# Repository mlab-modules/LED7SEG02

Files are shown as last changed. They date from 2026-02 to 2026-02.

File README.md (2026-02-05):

# LED7SEG02 - Project Documentation

Documentation for LED7SEG02 project - 7-segment display with WS2815 addressable RGB LEDs and RS485 communication.

## Project Overview

This project implements control of a 7-segment display consisting of 29 WS2815 RGB LEDs using STM32G031F8Px microcontroller. The display is controlled via RS485 bus using a defined protocol.

### Basic Specifications

- **MCU:** STM32G031F8Px (Cortex-M0+ @ 64MHz)
- **LEDs:** 29× WS2815 RGB (7 segments × 4 LEDs + 1 decimal point)
- **Communication:** RS485 @ 921600 baud
- **Power:** 3.3V (MCU), 12V (LEDs)

## Documentation Structure

### [WS2815_Driver_en.md](WS2815_Driver_en.md)
Complete WS2815 driver documentation including:
- API reference
- Visual effects library
- Usage examples
- Troubleshooting

### [Hardware_Configuration_en.md](Hardware_Configuration_en.md)
Hardware configuration and specifications:
- MCU pinout
- Peripheral settings
- Wiring diagram

### [protocol_en.md](protocol_en.md)
RS485 communication protocol:
- Frame structure
- Command list
- CRC-8 calculation
- Communication examples

### [firmware_en.md](firmware_en.md)
Firmware documentation:
- Software architecture
- Module descriptions
- Data flow

## Quick Start

### 1. Building the Project

Open project in **STM32CubeIDE**:

```
File → Open Projects from File System
→ Import source: LED7SEG02\sw
```

Build project: `Project → Build Project` (Ctrl+B)

### 2. Basic Usage

```c
#include "sw_ws2815.h"
#include "sw_effects.h"

void APP_Init(void) {
    WS2815_Init();
    WS2815_SetBrightness(50);
    Effects_Init();
    RS485_Init();
    Protocol_Init();
    RS485_StartReceive();
}

void APP_Main(void) {
    WS2815_Color_t green = {0, 255, 0};

    // Display digit
    WS2815_DisplayDigit(8, green, 1);
    WS2815_Update();
    while(WS2815_IsBusy());
}
```

### 3. Hardware Connection

```
PA0 (MCU) ──────► DI (WS2815)
GND (MCU) ──────► GND (WS2815)
12V PSU   ──────► +12V (WS2815)

PA2 (MCU) ──────► DI (MAX3485)
PA3 (MCU) ◄────── RO (MAX3485)
PA1 (MCU) ──────► DE/RE (MAX3485)
```

## Project Structure

```
LED7SEG02/
├── doc/                          # Documentation
│   ├── README.md                 # This file (CZ)
│   ├── README_en.md              # This file (EN)
│   ├── WS2815_Driver.md          # Driver documentation (CZ)
│   ├── WS2815_Driver_en.md       # Driver documentation (EN)
│   ├── Hardware_Configuration.md # Hardware documentation (CZ)
│   ├── Hardware_Configuration_en.md # Hardware documentation (EN)
│   ├── protocol_cz.md            # Protocol (CZ)
│   ├── protocol_en.md            # Protocol (EN)
│   ├── firmware_cz.md            # Firmware (CZ)
│   └── firmware_en.md            # Firmware (EN)
├── hw/                           # Hardware design files
├── sw/                           # Firmware
│   ├── Core/                     # STM32 HAL core
│   ├── Drivers/                  # STM32 HAL drivers
│   ├── src/                      # Application code
│   │   ├── app.c
│   │   └── app.h
│   ├── sw/                       # Custom drivers
│   │   ├── sw_ws2815.c/.h        # WS2815 driver
│   │   ├── sw_rs485.c/.h         # RS485 driver
│   │   └── sw_protocol.c/.h      # Communication protocol
│   └── sw_effects/               # Visual effects
│       ├── sw_effects.c/.h
│       └── README.md
└── app/                          # Python test application
    ├── led7seg_test.py
    └── config.json
```

## Key Features

### WS2815 Driver

- Hardware PWM + DMA (no bit-banging)
- 800 kHz bitrate
- Non-blocking operations
- Adjustable brightness (10-254)
- Precise timing (TIM2 @ 64MHz)
- Low CPU usage

### Visual Effects

- Rainbow - rainbow color cycle
- Spinning - spinning LED
- Breathing - breathing effect
- Segment Chase - running segments
- Knight Rider - K.I.T.T. effect
- Loading Bar - progress bar
- Rainbow Digit - digit with changing color
- Rainbow Gradient - digit with rainbow gradient

### RS485 Communication

- 921600 baud, 8N1
- Hardware RS485 mode (automatic DE control)
- Interrupt-based receive/transmit
- IDLE line detection for frame end
- CRC-8 validation
- Response time < 2ms

## Peripheral Configuration

| Peripheral | Pin | Function |
|---|---|---|
| TIM2_CH1 | PA0 | WS2815 Data |
| USART2_TX  | PA2 | RS485 TX |
| USART2_RX  | PA3 | RS485 RX |
| USART2_DE  | PA1 | RS485 Direction  |
| GPIO | PA4 | Address bit 0 |
| GPIO | PA12  | Address bit 1 |
| GPIO | PB0 | Address bit 2 |
| GPIO | PA11  | Address bit 3 |

## Segment Mapping

```
    aaaa
   f    b
   f    b
    gggg
   e    c
   e    c
    dddd  dp
```

| Segment | Index | LED positions |
|---|---|---|
| a | 0 | 0-3 |
| b | 1 | 4-7 |
| c | 2 | 8-11 |
| d | 3 | 12-15 |
| e | 4 | 16-19 |
| f | 5 | 20-23 |
| g | 6 | 24-27 |
| dp | 7 | 28 |

## API Quick Reference

### Initialization

```c
WS2815_Init();                      // Initialize driver
WS2815_SetBrightness(brightness);   // Set brightness (10-254)
Effects_Init();                     // Initialize effects
```

### Display Control

```c
WS2815_DisplayDigit(digit, color, show_dp);  // Display digit 0-9
WS2815_SetSegment(segment, color);           // Set segment
WS2815_SetLED(index, color);                 // Set LED
WS2815_Clear();                              // Turn off all LEDs
```

### Update

```c
WS2815_Update();                    // Send data (non-blocking)
WS2815_IsBusy();                    // Check if busy
```

### Effects

```c
Effects_Rainbow(step);                          // Rainbow effect
Effects_RainbowDigit(digit, show_dp, step);     // Rainbow on digit
Effects_Breathing(step, color);                 // Breathing
Effects_KnightRider(pos, color);                // K.I.T.T.
```

## Troubleshooting

### LEDs not lighting

1. Check 12V power supply
2. Check PA0 → DI wiring
3. Check common ground
4. Verify DMA buffer (WS2815_IsBusy)

### RS485 not communicating

1. Check baud rate (921600)
2. Verify A/B wire connections
3. Check BCD switch address
4. Measure DE pin activity

### Wrong colors

- Check brightness setting (range 10-254)
- Check power supply voltage (min 11V)

## Version History

### v1.0 (2026-02)

- WS2815 driver implementation
- RS485 communication with protocol
- Visual effects library
- Documentation

## License and Author

- **Project:** LED7SEG02
- **Author:** Richard Roztocil
- **Date:** February 2026

## References

- [WS2815 Datasheet](https://cdn-shop.adafruit.com/product-files/2757/WS2815.pdf)
- [STM32G031 Datasheet](https://www.st.com/resource/en/datasheet/stm32g031f8.pdf)
- [MAX3485 Datasheet](https://www.maximintegrated.com/en/products/interface/transceivers/MAX3485.html)

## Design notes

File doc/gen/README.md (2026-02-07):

# PCB

Board size: 74.6x128.54 mm (2.94x5.06 inches)

- This is the size of the rectangle that contains the board
- Thickness: 1.6 mm (63 mils)
- Material: FR4
- Finish: HAL
- Layers: 2
- Copper thickness: 35 µm

Solder mask: TOP / BOTTOM

- Color: Green

Silk screen: TOP / BOTTOM

- Color: White

# Important sizes

Clearance: 0.2 mm (8 mils)

Track width: 0.4 mm (16 mils)

- By design rules: 0.0 mm (0 mils)

Drill: 0.4 mm (16 mils)

- Vias: 0.4 mm (16 mils) [Design: 0.4 mm (16 mils)]
- Pads: 0.6 mm (24 mils)
- The above values are real drill sizes, they add 0.1 mm (4 mils) to plated holes (PTH)

Via: 0.6/0.3 mm (24/12 mils)

- By design rules: 0.5/0.3 mm (20/12 mils)
- Micro via: yes [0.2/0.1 mm (8/4 mils)]
- Buried/blind via: yes
- Total: 144 (thru: 144 buried/blind: 0 micro: 0)

Outer Annular Ring: 0.1 mm (4 mils)

- By design rules: 0.1 mm (4 mils)

Eurocircuits class: 8C
- Using min drill 0.35 mm for an OAR of 0.1 mm

# General stats

Components count: (SMD/THT)

- Top: 85/1 (SMD + THT)
- Bottom: 1/2 (SMD + THT)

Defined tracks:

Used tracks:

- 0.4 mm (16 mils) (474) defined: no
- 1.0 mm (39 mils) (97) defined: no

Defined vias:

Used vias:

- 0.6/0.3 mm (24/12 mils) (Count: 142, Aspect: 2.7 A) defined: no
- 1.0/0.6 mm (39/24 mils) (Count: 2, Aspect: 1.6 A) defined: no

Holes (excluding vias):

- 0.5 mm (20 mils) (5)
- 1.0 mm (39 mils) (12)

Oval holes:

Drill tools (including vias and computing adjusts and rounding):

- 0.4 mm (16 mils) (142)
- 0.6 mm (24 mils) (5)
- 0.7 mm (28 mils) (2)
- 1.1 mm (43 mils) (12)

Solder paste stats:

Using a paste with 87.75 % alloy, that has an specific gravity for the alloy of 7.4 g/cm³
and 1.0 g/cm³ for the flux. This paste has an specific gravity of  4.15 g/cm³.

The stencil thickness is  0.12 mm.

| Side | Pads with paste | Area [mm²] | Paste [g] |
|---|---|---|---|
| Top | 315 | 543.56 | 2.71 |
| Bottom | 6 | 18.00 | 0.09 |
| Total  | 321 | 561.56 | 2.80 |

Note: this is just an approximation to the theoretical value. Margins of the solder mask and waste aren't computed.

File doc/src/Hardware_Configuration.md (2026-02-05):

# LED7SEG02 - Hardware konfigurace

## MCU Specifikace

- **MCU:** STM32G031F8Px
- **Package:** TSSOP20
- **Core:** ARM Cortex-M0+ @ 64 MHz
- **Flash:** 64 KB
- **RAM:** 8 KB
- **Voltage:** 2.0V - 3.6V

## System Clock Configuration

```
HSI (16 MHz)
  └─> PLL (×8, ÷2)
       └─> SYSCLK: 64 MHz
            ├─> AHB: 64 MHz
            └─> APB: 64 MHz
```

### Clock Settings

```c
RCC_OscInitStruct.OscillatorType = RCC_OSCILLATORTYPE_HSI;
RCC_OscInitStruct.HSIState = RCC_HSI_ON;
RCC_OscInitStruct.HSIDiv = RCC_HSI_DIV1;
RCC_OscInitStruct.PLL.PLLState = RCC_PLL_ON;
RCC_OscInitStruct.PLL.PLLSource = RCC_PLLSOURCE_HSI;
RCC_OscInitStruct.PLL.PLLM = RCC_PLLM_DIV1;
RCC_OscInitStruct.PLL.PLLN = 8;
RCC_OscInitStruct.PLL.PLLR = RCC_PLLR_DIV2;
```

## Pinout

### Port A

| Pin | Funkce | Mód | Popis |
|-----|---|---|---|
| PA0 | TIM2_CH1 | AF | **WS2815 Data Output** |
| PA1 | USART2_DE | AF | RS485 Direction Enable |
| PA2 | USART2_TX | AF | RS485 Transmit |
| PA3 | USART2_RX | AF | RS485 Receive |
| PA4 | addr_0 | Input Pull-up | Adresa bit 0 (active LOW)  |
| PA11| addr_3 | Input Pull-up | Adresa bit 3 (active LOW)  |
| PA12| addr_1 | Input Pull-up | Adresa bit 1 (active LOW)  |
| PA13| SWDIO | Debug | SWD Data |
| PA14| SWCLK | Debug | SWD Clock |

### Port B

| Pin | Funkce | Mód | Popis |
|-----|---|---|---|
| PB0 | addr_2 | Input Pull-up | Adresa bit 2 (active LOW)  |

## Konfigurace periférií

### TIM2 (WS2815 PWM)

**Účel:** Generování přesného PWM signálu pro WS2815 LED protokol

```c
htim2.Instance = TIM2;
htim2.Init.Prescaler = 0;              // Bez dělení
htim2.Init.CounterMode = TIM_COUNTERMODE_UP;
htim2.Init.Period = 79;                // 1.25µs @ 64MHz
htim2.Init.ClockDivision = TIM_CLOCKDIVISION_DIV1;
htim2.Init.AutoReloadPreload = TIM_AUTORELOAD_PRELOAD_ENABLE;
```

**Channel 1 (PA0):**
- Mode: PWM Mode 1
- Duty cycle: Variable (24 nebo 52) pro bit encoding
- Řízeno DMA

### DMA1 Channel 1 (WS2815)

```c
hdma_ws2815.Instance = DMA1_Channel1;
hdma_ws2815.Init.Request = DMA_REQUEST_TIM2_CH1;
hdma_ws2815.Init.Direction = DMA_MEMORY_TO_PERIPH;
hdma_ws2815.Init.PeriphInc = DMA_PINC_DISABLE;
hdma_ws2815.Init.MemInc = DMA_MINC_ENABLE;
hdma_ws2815.Init.PeriphDataAlignment = DMA_PDATAALIGN_HALFWORD;
hdma_ws2815.Init.MemDataAlignment = DMA_MDATAALIGN_HALFWORD;
hdma_ws2815.Init.Mode = DMA_NORMAL;
hdma_ws2815.Init.Priority = DMA_PRIORITY_HIGH;
```

### USART2 (RS485)

**Účel:** RS485 komunikační rozhraní

```c
huart2.Instance = USART2;
huart2.Init.BaudRate = 921600;
huart2.Init.WordLength = UART_WORDLENGTH_8B;
huart2.Init.StopBits = UART_STOPBITS_1;
huart2.Init.Parity = UART_PARITY_NONE;
huart2.Init.Mode = UART_MODE_TX_RX;
huart2.Init.HwFlowCtl = UART_HWCONTROL_NONE;
huart2.Init.OverSampling = UART_OVERSAMPLING_16;
```

**RS485 Mode:**
- DE polarity: High
- DE assertion: 0 bit times
- DE deassertion: 0 bit times
- Automatické řízení DE pinu (hardware RS485 mode)

## GPIO Configuration

### WS2815 Data Pin (PA0)

```c
GPIO_InitStruct.Pin = GPIO_PIN_0;
GPIO_InitStruct.Mode = GPIO_MODE_AF_PP;      // Alternate Function Push-Pull
GPIO_InitStruct.Pull = GPIO_NOPULL;
GPIO_InitStruct.Speed = GPIO_SPEED_FREQ_HIGH;
GPIO_InitStruct.Alternate = GPIO_AF2_TIM2;   // TIM2_CH1
```

### RS485 Pins

```c
// TX (PA2) a RX (PA3)
GPIO_InitStruct.Pin = GPIO_PIN_2 | GPIO_PIN_3;
GPIO_InitStruct.Mode = GPIO_MODE_AF_PP;
GPIO_InitStruct.Pull = GPIO_NOPULL;
GPIO_InitStruct.Speed = GPIO_SPEED_FREQ_HIGH;
GPIO_InitStruct.Alternate = GPIO_AF1_USART2;

// DE (PA1)
GPIO_InitStruct.Pin = GPIO_PIN_1;
GPIO_InitStruct.Mode = GPIO_MODE_AF_PP;
GPIO_InitStruct.Pull = GPIO_NOPULL;
GPIO_InitStruct.Speed = GPIO_SPEED_FREQ_HIGH;
GPIO_InitStruct.Alternate = GPIO_AF1_USART2;
```

### Address Pins (BCD Switch)

```c
// addr_0 (PA4), addr_1 (PA12), addr_3 (PA11)
GPIO_InitStruct.Pin = GPIO_PIN_4 | GPIO_PIN_11 | GPIO_PIN_12;
GPIO_InitStruct.Mode = GPIO_MODE_INPUT;
GPIO_InitStruct.Pull = GPIO_PULLUP;

// addr_2 (PB0)
GPIO_InitStruct.Pin = GPIO_PIN_0;
GPIO_InitStruct.Mode = GPIO_MODE_INPUT;
GPIO_InitStruct.Pull = GPIO_PULLUP;
```

**Poznámka:** Adresové piny jsou aktivní v LOW (sepnutý přepínač = 0)

## Interrupt Configuration

### NVIC Priorities

| Přerušení | Priorita | Popis |
|---|---|---|
| DMA1_Channel1_IRQn  | 0 | WS2815 DMA (nejvyšší) |
| USART2_IRQn | 1 | RS485 komunikace |
| SysTick_IRQn | 3 | System tick timer |

### DMA1_Channel1_IRQHandler

```c
void DMA1_Channel1_IRQHandler(void)
{
    HAL_DMA_IRQHandler(&hdma_ws2815);
}
```

### USART2_IRQHandler

```c
void USART2_IRQHandler(void)
{
    RS485_IRQHandler();
}
```

## Schéma zapojení

### WS2815 LED Strip

```
STM32G031F8Px                    WS2815 LED Strip
┌─────────────┐                  ┌──────────┐
│             │                  │          │
│  PA0 (TIM2) ├─────────────────►│ DI       │
│             │   (Data)         │          │
│         GND ├─────────────────►│ GND      │
│             │                  │          │
└─────────────┘                  │ +12V     │◄─── 12V PSU
                                 └──────────┘
```

### RS485 Transceiver (MAX3485)

```
STM32G031F8Px                    MAX3485
┌─────────────┐                  ┌──────────┐
│             │                  │          │
│  PA2 (TX)   ├─────────────────►│ DI       │
│             │                  │          │
│  PA3 (RX)   │◄─────────────────┤ RO       │
│             │                  │          │
│  PA1 (DE)   ├─────────────────►│ DE       │
│             │        ┌────────►│ /RE      │
│             │        │         │          │
│         GND ├────────┴────────►│ GND      │
│             │                  │          │
│        3.3V ├─────────────────►│ VCC      │
│             │                  │          │
└─────────────┘                  │ A  ◄────►│ RS485 Bus
                                 │ B  ◄────►│
                                 └──────────┘
```

**Poznámka:** DE a /RE jsou spojeny - řízeny z PA1

### BCD Address Switch

```
STM32G031F8Px                    BCD Switch
┌─────────────┐                  ┌──────────┐
│             │                  │          │
│  PA4 (addr0)│◄─────────────────┤ bit 0    │
│             │                  │          │
│  PA12(addr1)│◄─────────────────┤ bit 1    │
│             │                  │          │
│  PB0 (addr2)│◄─────────────────┤ bit 2    │
│             │                  │          │
│  PA11(addr3)│◄─────────────────┤ bit 3    │
│             │                  │          │
│         GND ├─────────────────►│ Common   │
│             │                  │          │
└─────────────┘                  └──────────┘
```

**Poznámka:** Přepínače jsou aktivní v LOW (sepnutý = GND = 0)

## Poznámky k připojení

### Napájení

1. **MCU (3.3V):**
   - 100nF keramický kondenzátor na VDD/VSS (blízko MCU)
   - 10µF tantalový kondenzátor na VDD/VSS

2. **WS2815 (12V):**
   - Proud: ~60mA per LED při full white
   - Pro 29 LED: ~1.8A max
   - 1000µF elektrolytický kondenzátor na 12V vstupu

### Datová linka WS2815

- PA0 (3.3V logic) přímo na WS2815 DI
- Volitelně: 330Ω sériový rezistor pro ochranu
- Max délka kabelu: 5 metrů

### RS485 Bus

- Zakončovací odpor 120Ω na obou koncích sběrnice
- Twisted pair pro A/B vodiče
- Společná zem mezi zařízeními

## Spotřeba

### MCU

- Active mode @ 64MHz: ~15 mA
- Sleep mode: ~2 mA
- Stop mode: ~2 µA

### WS2815 LEDs

Per LED při 50% brightness:
- Red: 20 mA
- Green: 20 mA
- Blue: 20 mA
- White: 60 mA

Celkem pro 29 LED:
- All off: 0 mA
- All white @ 50%: ~0.9 A
- All white @ 100%: ~1.8 A

## Memory Map

### Flash (64 KB)

```
0x0800 0000 - 0x0800 FFFF    Flash memory
0x0800 0000 - 0x0800 0200    Interrupt vectors
0x0800 0200 - 0x0800 XXXX    Application code
0x0800 XXXX - 0x0800 FFFF    Constants/data
```

### RAM (8 KB)

```
0x2000 0000 - 0x2000 1FFF    SRAM
```

### RAM využití

| Buffer | Velikost | Popis |
|---|---|---|
| DMA buffer | ~2 KB | WS2815 data (29 LED × 24 bit + reset) |
| RX ring buffer | 64 B | RS485 příjem |
| TX buffer | 64 B | RS485 odesílání |
| Frame buffer | 64 B | Příchozí rámec |
| Response buffer | 13 B | Odpověď |

## HAL Configuration

### stm32g0xx_hal_conf.h

Povinné moduly:

```c
#define HAL_MODULE_ENABLED
#define HAL_TIM_MODULE_ENABLED      // Required for TIM2
#define HAL_DMA_MODULE_ENABLED      // Required for DMA
#define HAL_GPIO_MODULE_ENABLED
#define HAL_RCC_MODULE_ENABLED
#define HAL_CORTEX_MODULE_ENABLED
#define HAL_UART_MODULE_ENABLED     // For RS485
```

## Debug Configuration

### SWD

- **SWDIO:** PA13
- **SWCLK:** PA14

## Checklist pro oživení

- [ ] 3.3V napájení stabilní
- [ ] System clock 64 MHz ověřen
- [ ] SWD připojení funkční
- [ ] PA0 konfigurován jako TIM2_CH1
- [ ] TIM2 clock povolen
- [ ] DMA1 clock povolen
- [ ] WS2815 12V napájení připojeno
- [ ] Společná zem mezi MCU a LED
- [ ] První LED svítí s test kódem
- [ ] Všech 29 LED adresovatelných
- [ ] RS485 komunikace funkční
- [ ] BCD adresa správně čtena

## Troubleshooting

### PA0 nevysílá signál

1. Zkontrolovat GPIO clock: `__HAL_RCC_GPIOA_CLK_ENABLE()`
2. Zkontrolovat TIM2 clock: `__HAL_RCC_TIM2_CLK_ENABLE()`
3. Zkontrolovat alternate function: `GPIO_AF2_TIM2`
4. Měřit osciloskopem: Měl by být ~800kHz signál

### DMA nefunguje

1. Zkontrolovat DMA1 clock: `__HAL_RCC_DMA1_CLK_ENABLE()`
2. Zkontrolovat DMA request: `DMA_REQUEST_TIM2_CH1`
3. Zkontrolovat NVIC: `HAL_NVIC_EnableIRQ(DMA1_Channel1_IRQn)`
4. Zkontrolovat TIM2 DMA: `__HAL_TIM_ENABLE_DMA(&htim2, TIM_DMA_CC1)`

### RS485 nekomunikuje

1. Zkontrolovat baudrate (921600)
2. Zkontrolovat A/B zapojení (může být přehozené)
3. Měřit DE pin aktivitu při odesílání
4. Zkontrolovat zakončovací odpory

### Špatná adresa

1. Zkontrolovat pull-up na adresových pinech
2. Zkontrolovat že přepínače spínají k GND
3. Testovat jednotlivé bity

## Reference

- [STM32G031 Datasheet](https://www.st.com/resource/en/datasheet/stm32g031f8.pdf)
- [STM32G0 Reference Manual RM0444](https://www.st.com/resource/en/reference_manual/rm0444-stm32g0x0-advanced-armbased-32bit-mcus-stmicroelectronics.pdf)
- [WS2815 Datasheet](https://cdn-shop.adafruit.com/product-files/2757/WS2815.pdf)
- [MAX3485 Datasheet](https://www.maximintegrated.com/en/products/interface/transceivers/MAX3485.html)

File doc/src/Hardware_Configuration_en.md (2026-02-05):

# LED7SEG02 - Hardware Configuration

## MCU Specifications

- **MCU:** STM32G031F8Px
- **Package:** TSSOP20
- **Core:** ARM Cortex-M0+ @ 64 MHz
- **Flash:** 64 KB
- **RAM:** 8 KB
- **Voltage:** 2.0V - 3.6V

## System Clock Configuration

```
HSI (16 MHz)
  └─> PLL (×8, ÷2)
       └─> SYSCLK: 64 MHz
            ├─> AHB: 64 MHz
            └─> APB: 64 MHz
```

### Clock Settings

```c
RCC_OscInitStruct.OscillatorType = RCC_OSCILLATORTYPE_HSI;
RCC_OscInitStruct.HSIState = RCC_HSI_ON;
RCC_OscInitStruct.HSIDiv = RCC_HSI_DIV1;
RCC_OscInitStruct.PLL.PLLState = RCC_PLL_ON;
RCC_OscInitStruct.PLL.PLLSource = RCC_PLLSOURCE_HSI;
RCC_OscInitStruct.PLL.PLLM = RCC_PLLM_DIV1;
RCC_OscInitStruct.PLL.PLLN = 8;
RCC_OscInitStruct.PLL.PLLR = RCC_PLLR_DIV2;
```

## Pinout

### Port A

| Pin | Function | Mode | Description |
|-----|---|---|---|
| PA0 | TIM2_CH1 | AF | **WS2815 Data Output** |
| PA1 | USART2_DE | AF | RS485 Direction Enable |
| PA2 | USART2_TX | AF | RS485 Transmit |
| PA3 | USART2_RX | AF | RS485 Receive |
| PA4 | addr_0 | Input Pull-up | Address bit 0 (active LOW) |
| PA11| addr_3 | Input Pull-up | Address bit 3 (active LOW) |
| PA12| addr_1 | Input Pull-up | Address bit 1 (active LOW) |
| PA13| SWDIO | Debug | SWD Data |
| PA14| SWCLK | Debug | SWD Clock |

### Port B

| Pin | Function | Mode | Description |
|-----|---|---|---|
| PB0 | addr_2 | Input Pull-up | Address bit 2 (active LOW) |

## Peripheral Configuration

### TIM2 (WS2815 PWM)

**Purpose:** Generate precise PWM signal for WS2815 LED protocol

```c
htim2.Instance = TIM2;
htim2.Init.Prescaler = 0;              // No prescaling
htim2.Init.CounterMode = TIM_COUNTERMODE_UP;
htim2.Init.Period = 79;                // 1.25µs @ 64MHz
htim2.Init.ClockDivision = TIM_CLOCKDIVISION_DIV1;
htim2.Init.AutoReloadPreload = TIM_AUTORELOAD_PRELOAD_ENABLE;
```

**Channel 1 (PA0):**
- Mode: PWM Mode 1
- Duty cycle: Variable (24 or 52) for bit encoding
- Driven by DMA

### DMA1 Channel 1 (WS2815)

```c
hdma_ws2815.Instance = DMA1_Channel1;
hdma_ws2815.Init.Request = DMA_REQUEST_TIM2_CH1;
hdma_ws2815.Init.Direction = DMA_MEMORY_TO_PERIPH;
hdma_ws2815.Init.PeriphInc = DMA_PINC_DISABLE;
hdma_ws2815.Init.MemInc = DMA_MINC_ENABLE;
hdma_ws2815.Init.PeriphDataAlignment = DMA_PDATAALIGN_HALFWORD;
hdma_ws2815.Init.MemDataAlignment = DMA_MDATAALIGN_HALFWORD;
hdma_ws2815.Init.Mode = DMA_NORMAL;
hdma_ws2815.Init.Priority = DMA_PRIORITY_HIGH;
```

### USART2 (RS485)

**Purpose:** RS485 communication interface

```c
huart2.Instance = USART2;
huart2.Init.BaudRate = 921600;
huart2.Init.WordLength = UART_WORDLENGTH_8B;
huart2.Init.StopBits = UART_STOPBITS_1;
huart2.Init.Parity = UART_PARITY_NONE;
huart2.Init.Mode = UART_MODE_TX_RX;
huart2.Init.HwFlowCtl = UART_HWCONTROL_NONE;
huart2.Init.OverSampling = UART_OVERSAMPLING_16;
```

**RS485 Mode:**
- DE polarity: High
- DE assertion: 0 bit times
- DE deassertion: 0 bit times
- Automatic DE pin control (hardware RS485 mode)

## GPIO Configuration

### WS2815 Data Pin (PA0)

```c
GPIO_InitStruct.Pin = GPIO_PIN_0;
GPIO_InitStruct.Mode = GPIO_MODE_AF_PP;      // Alternate Function Push-Pull
GPIO_InitStruct.Pull = GPIO_NOPULL;
GPIO_InitStruct.Speed = GPIO_SPEED_FREQ_HIGH;
GPIO_InitStruct.Alternate = GPIO_AF2_TIM2;   // TIM2_CH1
```

### RS485 Pins

```c
// TX (PA2) and RX (PA3)
GPIO_InitStruct.Pin = GPIO_PIN_2 | GPIO_PIN_3;
GPIO_InitStruct.Mode = GPIO_MODE_AF_PP;
GPIO_InitStruct.Pull = GPIO_NOPULL;
GPIO_InitStruct.Speed = GPIO_SPEED_FREQ_HIGH;
GPIO_InitStruct.Alternate = GPIO_AF1_USART2;

// DE (PA1)
GPIO_InitStruct.Pin = GPIO_PIN_1;
GPIO_InitStruct.Mode = GPIO_MODE_AF_PP;
GPIO_InitStruct.Pull = GPIO_NOPULL;
GPIO_InitStruct.Speed = GPIO_SPEED_FREQ_HIGH;
GPIO_InitStruct.Alternate = GPIO_AF1_USART2;
```

### Address Pins (BCD Switch)

```c
// addr_0 (PA4), addr_1 (PA12), addr_3 (PA11)
GPIO_InitStruct.Pin = GPIO_PIN_4 | GPIO_PIN_11 | GPIO_PIN_12;
GPIO_InitStruct.Mode = GPIO_MODE_INPUT;
GPIO_InitStruct.Pull = GPIO_PULLUP;

// addr_2 (PB0)
GPIO_InitStruct.Pin = GPIO_PIN_0;
GPIO_InitStruct.Mode = GPIO_MODE_INPUT;
GPIO_InitStruct.Pull = GPIO_PULLUP;
```

**Note:** Address pins are active LOW (closed switch = 0)

## Interrupt Configuration

### NVIC Priorities

| Interrupt | Priority | Description |
|---|---|---|
| DMA1_Channel1_IRQn  | 0 | WS2815 DMA (highest) |
| USART2_IRQn | 1 | RS485 communication |
| SysTick_IRQn | 3 | System tick timer |

### DMA1_Channel1_IRQHandler

```c
void DMA1_Channel1_IRQHandler(void)
{
    HAL_DMA_IRQHandler(&hdma_ws2815);
}
```

### USART2_IRQHandler

```c
void USART2_IRQHandler(void)
{
    RS485_IRQHandler();
}
```

## Wiring Diagrams

### WS2815 LED Strip

```
STM32G031F8Px                    WS2815 LED Strip
┌─────────────┐                  ┌──────────┐
│             │                  │          │
│  PA0 (TIM2) ├─────────────────►│ DI       │
│             │   (Data)         │          │
│         GND ├─────────────────►│ GND      │
│             │                  │          │
└─────────────┘                  │ +12V     │◄─── 12V PSU
                                 └──────────┘
```

### RS485 Transceiver (MAX3485)

```
STM32G031F8Px                    MAX3485
┌─────────────┐                  ┌──────────┐
│             │                  │          │
│  PA2 (TX)   ├─────────────────►│ DI       │
│             │                  │          │
│  PA3 (RX)   │◄─────────────────┤ RO       │
│             │                  │          │
│  PA1 (DE)   ├─────────────────►│ DE       │
│             │        ┌────────►│ /RE      │
│             │        │         │          │
│         GND ├────────┴────────►│ GND      │
│             │                  │          │
│        3.3V ├─────────────────►│ VCC      │
│             │                  │          │
└─────────────┘                  │ A  ◄────►│ RS485 Bus
                                 │ B  ◄────►│
                                 └──────────┘
```

**Note:** DE and /RE are connected - controlled from PA1

### BCD Address Switch

```
STM32G031F8Px                    BCD Switch
┌─────────────┐                  ┌──────────┐
│             │                  │          │
│  PA4 (addr0)│◄─────────────────┤ bit 0    │
│             │                  │          │
│  PA12(addr1)│◄─────────────────┤ bit 1    │
│             │                  │          │
│  PB0 (addr2)│◄─────────────────┤ bit 2    │
│             │                  │          │
│  PA11(addr3)│◄─────────────────┤ bit 3    │
│             │                  │          │
│         GND ├─────────────────►│ Common   │
│             │                  │          │
└─────────────┘                  └──────────┘
```

**Note:** Switches are active LOW (closed = GND = 0)

## Connection Notes

### Power Supply

1. **MCU (3.3V):**
   - 100nF ceramic capacitor on VDD/VSS (close to MCU)
   - 10µF tantalum capacitor on VDD/VSS

2. **WS2815 (12V):**
   - Current: ~60mA per LED at full white
   - For 29 LEDs: ~1.8A max
   - 1000µF electrolytic capacitor on 12V input

### WS2815 Data Line

- PA0 (3.3V logic) directly to WS2815 DI
- Optional: 330Ω series resistor for protection
- Max cable length: 5 meters

### RS485 Bus

- 120Ω termination resistor at both ends of bus
- Twisted pair for A/B wires
- Common ground between devices

## Power Consumption

### MCU

- Active mode @ 64MHz: ~15 mA
- Sleep mode: ~2 mA
- Stop mode: ~2 µA

### WS2815 LEDs

Per LED at 50% brightness:
- Red: 20 mA
- Green: 20 mA
- Blue: 20 mA
- White: 60 mA

Total for 29 LEDs:
- All off: 0 mA
- All white @ 50%: ~0.9 A
- All white @ 100%: ~1.8 A

## Memory Map

### Flash (64 KB)

```
0x0800 0000 - 0x0800 FFFF    Flash memory
0x0800 0000 - 0x0800 0200    Interrupt vectors
0x0800 0200 - 0x0800 XXXX    Application code
0x0800 XXXX - 0x0800 FFFF    Constants/data
```

### RAM (8 KB)

```
0x2000 0000 - 0x2000 1FFF    SRAM
```

### RAM Usage

| Buffer | Size | Description |
|---|---|---|
| DMA buffer | ~2 KB | WS2815 data (29 LEDs × 24 bits + reset) |
| RX ring buffer | 64 B | RS485 reception |
| TX buffer | 64 B | RS485 transmission |
| Frame buffer | 64 B | Incoming frame |
| Response buffer | 13 B | Response |

## HAL Configuration

### stm32g0xx_hal_conf.h

Required modules:

```c
#define HAL_MODULE_ENABLED
#define HAL_TIM_MODULE_ENABLED      // Required for TIM2
#define HAL_DMA_MODULE_ENABLED      // Required for DMA
#define HAL_GPIO_MODULE_ENABLED
#define HAL_RCC_MODULE_ENABLED
#define HAL_CORTEX_MODULE_ENABLED
#define HAL_UART_MODULE_ENABLED     // For RS485
```

## Debug Configuration

### SWD

- **SWDIO:** PA13
- **SWCLK:** PA14

## Board Bring-up Checklist

- [ ] 3.3V power supply stable
- [ ] System clock 64 MHz verified
- [ ] SWD connection working
- [ ] PA0 configured as TIM2_CH1
- [ ] TIM2 clock enabled
- [ ] DMA1 clock enabled
- [ ] WS2815 12V power supply connected
- [ ] Common ground between MCU and LEDs
- [ ] First LED lights up with test code
- [ ] All 29 LEDs addressable
- [ ] RS485 communication working
- [ ] BCD address read correctly

## Troubleshooting

### PA0 not outputting signal

1. Check GPIO clock: `__HAL_RCC_GPIOA_CLK_ENABLE()`
2. Check TIM2 clock: `__HAL_RCC_TIM2_CLK_ENABLE()`
3. Check alternate function: `GPIO_AF2_TIM2`
4. Measure with oscilloscope: Should see ~800kHz signal

### DMA not working

1. Check DMA1 clock: `__HAL_RCC_DMA1_CLK_ENABLE()`
2. Check DMA request: `DMA_REQUEST_TIM2_CH1`
3. Check NVIC: `HAL_NVIC_EnableIRQ(DMA1_Channel1_IRQn)`
4. Check TIM2 DMA: `__HAL_TIM_ENABLE_DMA(&htim2, TIM_DMA_CC1)`

### RS485 not communicating

1. Check baud rate (921600)
2. Check A/B wiring (may be swapped)
3. Measure DE pin activity during transmission
4. Check termination resistors

### Wrong address

1. Check pull-up on address pins
2. Check that switches connect to GND
3. Test individual bits

## References

- [STM32G031 Datasheet](https://www.st.com/resource/en/datasheet/stm32g031f8.pdf)
- [STM32G0 Reference Manual RM0444](https://www.st.com/resource/en/reference_manual/rm0444-stm32g0x0-advanced-armbased-32bit-mcus-stmicroelectronics.pdf)
- [WS2815 Datasheet](https://cdn-shop.adafruit.com/product-files/2757/WS2815.pdf)
- [MAX3485 Datasheet](https://www.maximintegrated.com/en/products/interface/transceivers/MAX3485.html)

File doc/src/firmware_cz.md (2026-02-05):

# LED7SEG02 - Dokumentace firmware

## Přehled

Firmware pro 7-segmentový displej s adresovatelnými RGB LED WS2815 a RS485 komunikací.

### Hardware

- **MCU**: STM32G031F8PX (Cortex-M0+, 64KB Flash, 8KB RAM)
- **Taktování**: 64 MHz
- **LED**: WS2815 RGB (29 LED - 7 segmentů × 4 LED + 1 desetinná tečka)
- **Komunikace**: RS485 přes MAX3485 transceiver
- **Napájení**: 12V pro WS2815

### Pinout

| Pin | Funkce | Popis |
|-----|---|---|
| PA2 | USART2_TX | RS485 TX (k MAX3485 DI) |
| PA3 | USART2_RX | RS485 RX (z MAX3485 RO) |
| PA1 | USART2_DE | RS485 DE/RE řízení |
| PA0 | TIM2_CH1 | WS2815 data (přes DMA) |
| PA4 | GPIO Input | Adresa bit 0 |
| PA12 | GPIO Input | Adresa bit 1 |
| PB0 | GPIO Input | Adresa bit 2 |
| PA11 | GPIO Input | Adresa bit 3 |

## Architektura software

### Struktura projektu

```
sw/
├── Core/                    # STM32 HAL a konfigurace
│   ├── Inc/
│   └── Src/
│       ├── main.c          # Hlavní smyčka, inicializace
│       ├── stm32g0xx_it.c  # Interrupt handlery
│       └── stm32g0xx_hal_msp.c
├── src/
│   ├── app.c               # Aplikační logika
│   └── app.h
├── sw/
│   ├── sw_ws2815.c/.h      # WS2815 LED driver
│   ├── sw_rs485.c/.h       # RS485 driver
│   └── sw_protocol.c/.h    # Komunikační protokol
└── sw_effects/
    ├── sw_effects.c/.h     # Vizuální efekty
    └── README.md
```

### Moduly

#### sw_ws2815 - WS2815 Driver

Ovládání adresovatelných RGB LED pomocí TIM3 + DMA.

**Časování WS2815:**
- Perioda: 1.25µs (800kHz)
- T0H: 375ns, T0L: 875ns
- T1H: 812.5ns, T1L: 437.5ns
- Reset: >280µs

**Hlavní funkce:**
```c
void WS2815_Init(void);
void WS2815_SetLED(uint8_t index, WS2815_Color_t color);
void WS2815_SetSegment(uint8_t segment, WS2815_Color_t color);
void WS2815_DisplayDigit(uint8_t digit, WS2815_Color_t color, uint8_t show_dp);
void WS2815_SetBrightness(uint8_t brightness);
void WS2815_Update(void);
void WS2815_Clear(void);
uint8_t WS2815_IsBusy(void);
```

#### sw_rs485 - RS485 Driver

Interrupt-based RS485 komunikace s ring bufferem.

**Vlastnosti:**
- RXNE interrupt pro příjem bytů
- IDLE line detection pro detekci konce rámce
- TXE/TC interrupts pro odesílání
- Hardware RS485 mód (automatické DE řízení)

**Hlavní funkce:**
```c
RS485_Status_t RS485_Init(void);
RS485_Status_t RS485_StartReceive(void);
RS485_Status_t RS485_TransmitIT(uint8_t *data, uint16_t length);
void RS485_SetFrameCallback(RS485_FrameCallback_t callback);
uint8_t RS485_Available(void);
uint8_t RS485_Read(void);
void RS485_IRQHandler(void);
```

#### sw_protocol - Komunikační protokol

Zpracování příkazů a odpovědí.

**Vlastnosti:**
- Zpracování rámce v IDLE přerušení (minimální latence)
- Odložená aktualizace displeje (DMA safe)
- CRC-8 validace

**Hlavní funkce:**
```c
void Protocol_Init(void);
void Protocol_Process(void);
void Protocol_HandleFrame(uint8_t *data, uint8_t length);
uint8_t Protocol_GetAddress(void);
```

#### sw_effects - Vizuální efekty

Knihovna předpřipravených animací.

**Dostupné efekty:**
- Rainbow - duhový cyklus
- Spinning - kroužící LED
- Breathing - dýchací efekt
- Segment Chase - běžící segmenty
- Knight Rider - K.I.T.T. efekt
- Loading Bar - progress bar
- Rainbow Digit - číslice s měnící se barvou
- Rainbow Gradient - číslice s duhovým gradientem

## Tok dat

### Příjem a zpracování příkazu

```
1. RXNE interrupt → byte do ring bufferu a frame bufferu
2. IDLE interrupt → Protocol_HandleFrame() volán
3. Rámec parsován a validován (CRC)
4. Příkaz zpracován, stav aktualizován
5. Odpověď odeslána (TX interrupt)
6. display_update_pending flag nastaven
7. Main loop → Protocol_Process() → UpdateDisplay()
8. WS2815_Update() → DMA transfer → LED aktualizovány
```

### Časování odpovědi

- Firmware zpracování: <100µs
- Celková odezva: ~1.5ms (limitováno USB převodníkem)

## Konfigurace

### USART2 (RS485)

```c
BaudRate = 921600
WordLength = 8 bits
StopBits = 1
Parity = None
Mode = TX_RX
HwFlowCtl = None
OverSampling = 16
DE Polarity = High
```

### TIM3 (WS2815)

```c
Prescaler = 0
Period = 79 (80 cyklů = 1.25µs při 64MHz)
Channel 1 PWM mode
DMA Circular mode
```

### NVIC Priority

| Přerušení | Priorita | Popis |
|---|---|---|
| DMA1_Channel1 | 0 | WS2815 (nejvyšší) |
| USART2 | 1 | RS485 komunikace |
| SysTick | 3 | HAL timing |

## Paměťová mapa

| Oblast | Velikost | Použití |
|---|---|---|
| Flash | 64 KB | Kód + konstanty |
| RAM | 8 KB | Proměnné + buffery |

### RAM využití

| Buffer | Velikost | Popis |
|---|---|---|
| DMA buffer | ~2 KB | WS2815 data (29 LED × 24 bit + reset) |
| RX ring buffer | 64 B | RS485 příjem |
| TX buffer | 64 B | RS485 odesílání |
| Frame buffer | 64 B | Příchozí rámec |
| Response buffer | 13 B | Odpověď |

## Kompilace a programování

### Požadavky

- STM32CubeIDE nebo ARM GCC toolchain
- ST-Link programmer

### Kompilace

```bash
cd sw/Debug
make clean
make all
```

### Programování

```bash
st-flash write LED7SEG02.bin 0x08000000
```

Nebo pomocí STM32CubeIDE: Run → Debug/Run

## Řešení problémů

### LED nesvítí

1. Zkontrolujte 12V napájení
2. Ověřte DMA buffer (WS2815_IsBusy)
3. Zkontrolujte timing signálu osciloskopem

### RS485 nekomunikuje

1. Zkontrolujte baudrate (921600)
2. Ověřte zapojení A/B vodičů
3. Zkontrolujte adresu BCD přepínačů
4. Změřte DE pin aktivitu

### Pomalá odezva

1. Ověřte zpracování v IDLE přerušení
2. Zkontrolujte priority přerušení
3. USB převodník může být bottleneck

## Verze

| Verze | Datum | Změny |
|---|---|---|
| 1.0 | 2026-02 | První verze |

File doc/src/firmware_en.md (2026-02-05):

# LED7SEG02 - Firmware Documentation

## Overview

Firmware for 7-segment display with addressable WS2815 RGB LEDs and RS485 communication.

### Hardware

- **MCU**: STM32G031F8PX (Cortex-M0+, 64KB Flash, 8KB RAM)
- **Clock**: 64 MHz
- **LEDs**: WS2815 RGB (29 LEDs - 7 segments × 4 LEDs + 1 decimal point)
- **Communication**: RS485 via MAX3485 transceiver
- **Power**: 12V for WS2815

### Pinout

| Pin | Function | Description |
|-----|---|---|
| PA2 | USART2_TX | RS485 TX (to MAX3485 DI) |
| PA3 | USART2_RX | RS485 RX (from MAX3485 RO) |
| PA1 | USART2_DE | RS485 DE/RE control |
| PA0 | TIM2_CH1 | WS2815 data (via DMA) |
| PA4 | GPIO Input | Address bit 0 |
| PA12 | GPIO Input | Address bit 1 |
| PB0 | GPIO Input | Address bit 2 |
| PA11 | GPIO Input | Address bit 3 |

## Software Architecture

### Project Structure

```
sw/
├── Core/                    # STM32 HAL and configuration
│   ├── Inc/
│   └── Src/
│       ├── main.c          # Main loop, initialization
│       ├── stm32g0xx_it.c  # Interrupt handlers
│       └── stm32g0xx_hal_msp.c
├── src/
│   ├── app.c               # Application logic
│   └── app.h
├── sw/
│   ├── sw_ws2815.c/.h      # WS2815 LED driver
│   ├── sw_rs485.c/.h       # RS485 driver
│   └── sw_protocol.c/.h    # Communication protocol
└── sw_effects/
    ├── sw_effects.c/.h     # Visual effects
    └── README.md
```

### Modules

#### sw_ws2815 - WS2815 Driver

Controls addressable RGB LEDs using TIM3 + DMA.

**WS2815 Timing:**
- Period: 1.25µs (800kHz)
- T0H: 375ns, T0L: 875ns
- T1H: 812.5ns, T1L: 437.5ns
- Reset: >280µs

**Main Functions:**
```c
void WS2815_Init(void);
void WS2815_SetLED(uint8_t index, WS2815_Color_t color);
void WS2815_SetSegment(uint8_t segment, WS2815_Color_t color);
void WS2815_DisplayDigit(uint8_t digit, WS2815_Color_t color, uint8_t show_dp);
void WS2815_SetBrightness(uint8_t brightness);
void WS2815_Update(void);
void WS2815_Clear(void);
uint8_t WS2815_IsBusy(void);
```

#### sw_rs485 - RS485 Driver

Interrupt-based RS485 communication with ring buffer.

**Features:**
- RXNE interrupt for byte reception
- IDLE line detection for frame end
- TXE/TC interrupts for transmission
- Hardware RS485 mode (automatic DE control)

**Main Functions:**
```c
RS485_Status_t RS485_Init(void);
RS485_Status_t RS485_StartReceive(void);
RS485_Status_t RS485_TransmitIT(uint8_t *data, uint16_t length);
void RS485_SetFrameCallback(RS485_FrameCallback_t callback);
uint8_t RS485_Available(void);
uint8_t RS485_Read(void);
void RS485_IRQHandler(void);
```

#### sw_protocol - Communication Protocol

Command and response processing.

**Features:**
- Frame processing in IDLE interrupt (minimal latency)
- Deferred display update (DMA safe)
- CRC-8 validation

**Main Functions:**
```c
void Protocol_Init(void);
void Protocol_Process(void);
void Protocol_HandleFrame(uint8_t *data, uint8_t length);
uint8_t Protocol_GetAddress(void);
```

#### sw_effects - Visual Effects

Library of pre-built animations.

**Available Effects:**
- Rainbow - rainbow color cycle
- Spinning - spinning LED
- Breathing - breathing effect
- Segment Chase - running segments
- Knight Rider - K.I.T.T. effect
- Loading Bar - progress bar
- Rainbow Digit - digit with changing color
- Rainbow Gradient - digit with rainbow gradient

## Data Flow

### Command Reception and Processing

```
1. RXNE interrupt → byte to ring buffer and frame buffer
2. IDLE interrupt → Protocol_HandleFrame() called
3. Frame parsed and validated (CRC)
4. Command processed, state updated
5. Response sent (TX interrupt)
6. display_update_pending flag set
7. Main loop → Protocol_Process() → UpdateDisplay()
8. WS2815_Update() → DMA transfer → LEDs updated
```

### Response Timing

- Firmware processing: <100µs
- Total response time: ~1.5ms (limited by USB converter)

## Configuration

### USART2 (RS485)

```c
BaudRate = 921600
WordLength = 8 bits
StopBits = 1
Parity = None
Mode = TX_RX
HwFlowCtl = None
OverSampling = 16
DE Polarity = High
```

### TIM3 (WS2815)

```c
Prescaler = 0
Period = 79 (80 cycles = 1.25µs at 64MHz)
Channel 1 PWM mode
DMA Circular mode
```

### NVIC Priority

| Interrupt | Priority | Description |
|---|---|---|
| DMA1_Channel1 | 0 | WS2815 (highest) |
| USART2 | 1 | RS485 communication |
| SysTick | 3 | HAL timing |

## Memory Map

| Region | Size | Usage |
|---|---|---|
| Flash | 64 KB | Code + constants |
| RAM | 8 KB | Variables + buffers |

### RAM Usage

| Buffer | Size | Description |
|---|---|---|
| DMA buffer | ~2 KB | WS2815 data (29 LEDs × 24 bits + reset) |
| RX ring buffer | 64 B | RS485 reception |
| TX buffer | 64 B | RS485 transmission |
| Frame buffer | 64 B | Incoming frame |
| Response buffer | 13 B | Response |

## Building and Programming

### Requirements

- STM32CubeIDE or ARM GCC toolchain
- ST-Link programmer

### Building

```bash
cd sw/Debug
make clean
make all
```

### Programming

```bash
st-flash write LED7SEG02.bin 0x08000000
```

Or using STM32CubeIDE: Run → Debug/Run

## Troubleshooting

### LEDs not lighting

1. Check 12V power supply
2. Verify DMA buffer (WS2815_IsBusy)
3. Check signal timing with oscilloscope

### RS485 not communicating

1. Check baud rate (921600)
2. Verify A/B wire connections
3. Check BCD switch address
4. Measure DE pin activity

### Slow response

1. Verify processing in IDLE interrupt
2. Check interrupt priorities
3. USB converter may be bottleneck

## Version History

| Version | Date | Changes |
|---|---|---|
| 1.0 | 2026-02 | Initial release |

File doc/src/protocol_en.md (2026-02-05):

# LED7SEG02 - RS485 Communication Protocol

## Overview

Protocol for controlling 7-segment display with WS2815 LEDs over RS485 bus.

- **Physical layer**: RS485 half-duplex
- **Baud rate**: 921600 (configurable)
- **Format**: 8N1 (8 data bits, no parity, 1 stop bit)
- **Transceiver**: MAX3485 with automatic DE pin control

## Frame Structure

```
[START][ADDR][CMD][DATA 0-8B][CRC8][END]
```

| Field | Size | Value | Description |
|---|---|---|---|
| START | 1 byte | 0xAA | Frame start marker |
| ADDR | 1 byte | 0x00-0x0F | Device address |
| CMD | 1 byte | see table | Command |
| DATA | 0-8 bytes | - | Command data |
| CRC8 | 1 byte | - | Checksum |
| END | 1 byte | 0x55 | Frame end marker |

## Addressing

- **0x00**: Broadcast (all devices, no response)
- **0x01-0x0F**: Unicast (specific device with response)

Device address is set using BCD switches on pins:
- PA4 = bit 0 (weight 1)
- PA12 = bit 1 (weight 2)
- PB0 = bit 2 (weight 4)
- PA11 = bit 3 (weight 8)

Switches are active LOW (closed = 0).

## Commands

### Display Control

| Command | Code | Data | Description |
|---|---|---|---|
| SET_DIGIT | 0x01 | [digit][dp] | Display digit 0-9, dp=decimal point |
| SET_COLOR | 0x02 | [R][G][B] | Set RGB color |
| SET_BRIGHTNESS | 0x03 | [brightness] | Set brightness 0-255 |
| SET_EFFECT | 0x04 | [effect][speed] | Start effect |
| SET_SEGMENT | 0x05 | [seg][R][G][B] | Set segment 0-7 color |
| SET_LED | 0x06 | [idx][R][G][B] | Set LED 0-28 color |
| CLEAR | 0x10 | - | Turn off display |
| UPDATE | 0x11 | - | Force LED update |

### Queries

| Command | Code | Response | Description |
|---|---|---|---|
| GET_STATUS | 0xF0 | 8 bytes status | Returns current state |
| GET_VERSION | 0xF1 | [major][minor] | Returns FW version |
| GET_ADDRESS | 0xF2 | [addr] | Returns device address |
| PING | 0xFF | - | Communication test |

## Effects

| Effect | Code | Description |
|---|---|---|
| STOP | 0x00 | Stop effect |
| RAINBOW | 0x01 | Rainbow cycle |
| SPINNING | 0x02 | Spinning LED |
| BREATHING | 0x03 | Breathing effect |
| SEGMENT_CHASE | 0x04 | Running segments |
| KNIGHT_RIDER | 0x05 | K.I.T.T. effect |
| LOADING_BAR | 0x06 | Progress bar |
| RAINBOW_DIGIT | 0x07 | Digit with changing color |
| RAINBOW_GRADIENT | 0x08 | Digit with rainbow gradient |

## Response Status Codes

| Status | Code | Description |
|---|---|---|
| OK | 0x00 | Command executed successfully |
| UNKNOWN_CMD | 0x01 | Unknown command |
| INVALID_PARAM | 0x02 | Invalid parameter |
| BUSY | 0x03 | Device busy |
| CRC_ERROR | 0x04 | CRC error |

## CRC-8 Calculation

Polynomial: **0x07** (x^8 + x^2 + x + 1)

CRC is calculated over ADDR + CMD + DATA fields.

### Algorithm (C)

```c
uint8_t crc8(uint8_t *data, uint8_t length) {
    uint8_t crc = 0x00;
    for (uint8_t i = 0; i < length; i++) {
        crc ^= data[i];
        for (uint8_t j = 0; j < 8; j++) {
            if (crc & 0x80) {
                crc = (crc << 1) ^ 0x07;
            } else {
                crc <<= 1;
            }
        }
    }
    return crc;
}
```

### Algorithm (Python)

```python
def crc8(data: bytes) -> int:
    crc = 0x00
    for byte in data:
        crc ^= byte
        for _ in range(8):
            if crc & 0x80:
                crc = (crc << 1) ^ 0x07
            else:
                crc <<= 1
            crc &= 0xFF
    return crc
```

### Calculation Example

PING command to address 0x01:
```
Data for CRC: [0x01, 0xFF]  (ADDR=0x01, CMD=0xFF)
CRC = 0xD3

Complete frame: AA 01 FF D3 55
```

## Communication Examples

### PING

```
TX: AA 01 FF D3 55
RX: AA 01 00 3E 55
```

### SET_DIGIT (display "5" with decimal point)

```
TX: AA 01 01 05 01 XX 55   (XX = CRC)
RX: AA 01 00 XX 55
```

### SET_COLOR (green)

```
TX: AA 01 02 00 FF 00 XX 55
RX: AA 01 00 XX 55
```

### Broadcast SET_BRIGHTNESS

```
TX: AA 00 03 32 XX 55      (address 0x00 = broadcast)
(no response)
```

## Timing

- **Frame timeout**: 100ms (if frame is incomplete)
- **Typical response time**: <2ms (depends on USB converter)
- **Minimum gap between commands**: recommended to wait for response

## Segment Mapping

```
    aaaa
   f    b
   f    b
    gggg
   e    c
   e    c
    dddd  dp
```

| Segment | Index | LED positions |
|---|---|---|
| a | 0 | 0-3 |
| b | 1 | 4-7 |
| c | 2 | 8-11 |
| d | 3 | 12-15 |
| e | 4 | 16-19 |
| f | 5 | 20-23 |
| g | 6 | 24-27 |
| dp | 7 | 28 |

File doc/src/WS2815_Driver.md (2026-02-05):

# WS2815 LED Driver - Dokumentace

## Přehled

Driver pro ovládání adresovatelných RGB LED WS2815 na platformě STM32G031F8Px. Driver využívá TIM2 + DMA pro generování přesného PWM signálu kompatibilního s WS2815 protokolem.

## Specifikace

- **MCU:** STM32G031F8Px (Cortex-M0+)
- **Systémový takt:** 64 MHz
- **LED typ:** WS2815 RGB addressable LEDs
- **Komunikace:** 1-wire, 800 kHz bitrate
- **Počet LED:** 29 (7 segmentů × 4 LED + 1 desetinná tečka)
- **Barevný formát:** GRB (Green-Red-Blue)

## Hardware konfigurace

### Připojení

| Signál | Pin MCU | Periférie | Popis |
|---|---|---|---|
| Data | PA0 | TIM2_CH1  | Data signál pro WS2815 |
| VCC | - | - | 12V napájení pro LED |
| GND | GND | - | Společná zem |

### Periférie

- **TIM2:** Timer pro PWM generování
  - Channel 1 (PA0)
  - Frekvence: 800 kHz
  - Prescaler: 0
  - Period: 79 (@ 64MHz = 1.25µs)

- **DMA1 Channel 1:** Přenos PWM dat
  - Request: TIM2_CH1
  - Direction: Memory-to-Peripheral
  - Mode: Normal
  - Priority: High (0)

## WS2815 Timing

WS2815 používá následující časování:

| Bit | T0H | T0L | T1H | T1L | Celkem |
|-----|---|---|---|---|---|
| 0 | 375ns  | 875ns | - | - | 1.25µs |
| 1 | - | - | 812.5ns | 437.5ns| 1.25µs |
| RES | - | >280µs  | - | - | - |

### Implementace v driveru

```c
#define WS2815_TIM_PERIOD   80    // 1.25µs @ 64MHz
#define WS2815_BIT_0_DUTY   24    // 375ns (30% duty)
#define WS2815_BIT_1_DUTY   52    // 812.5ns (65% duty)
#define WS2815_RESET_SLOTS  250   // >280µs reset perioda
```

## Struktura souborů

```
LED7SEG02/sw/
├── sw/
│   ├── sw_ws2815.c       # Driver implementace
│   └── sw_ws2815.h       # Public API
├── sw_effects/
│   ├── sw_effects.c      # Knihovna efektů
│   └── sw_effects.h
├── Core/
│   └── Src/
│       └── stm32g0xx_it.c  # DMA interrupt handler
└── src/
    └── app.c             # Aplikační kód
```

## API Reference

### Datové typy

```c
typedef struct {
    uint8_t r;  // Red (0-255)
    uint8_t g;  // Green (0-255)
    uint8_t b;  // Blue (0-255)
} WS2815_Color_t;
```

### Funkce

#### WS2815_Init()

```c
void WS2815_Init(void);
```

Inicializuje WS2815 driver (GPIO, TIM2, DMA).

---

#### WS2815_SetLED()

```c
void WS2815_SetLED(uint8_t index, WS2815_Color_t color);
```

Nastaví barvu jedné LED v bufferu.

**Parametry:**
- `index`: Index LED (0-28)
- `color`: RGB barva

**Poznámka:** Změna se projeví až po volání `WS2815_Update()`

---

#### WS2815_SetSegment()

```c
void WS2815_SetSegment(uint8_t segment, WS2815_Color_t color);
```

Nastaví barvu celého segmentu (4 LED).

**Parametry:**
- `segment`: Index segmentu (0-7)
- `color`: RGB barva

---

#### WS2815_DisplayDigit()

```c
void WS2815_DisplayDigit(uint8_t digit, WS2815_Color_t color, uint8_t show_dp);
```

Zobrazí číslici 0-9 na displeji.

**Parametry:**
- `digit`: Číslice (0-9)
- `color`: RGB barva
- `show_dp`: 1 = zobrazit desetinnou tečku

---

#### WS2815_Update()

```c
void WS2815_Update(void);
```

Odešle buffer do LED pásku pomocí DMA.

**Poznámka:** Funkce je neblokující, používá DMA transfer

---

#### WS2815_Clear()

```c
void WS2815_Clear(void);
```

Vypne všechny LED (nastaví na černou).

---

#### WS2815_SetBrightness()

```c
void WS2815_SetBrightness(uint8_t brightness);
```

Nastaví globální jas všech LED.

**Parametry:**
- `brightness`: 0 (vypnuto), 10-254 (funkční rozsah)

**Poznámky:**
- Hodnoty 1-9 se automaticky nastaví na 10
- Hodnoty > 254 se automaticky nastaví na 254

---

#### WS2815_IsBusy()

```c
uint8_t WS2815_IsBusy(void);
```

Zkontroluje, zda probíhá DMA transfer.

**Return:** 1 pokud je zaneprázdněn, 0 pokud je volný

## Knihovna efektů (sw_effects)

### Dostupné efekty

| Funkce | Popis |
|---|---|
| `Effects_Rainbow(step)` | Duhový cyklus na všech LED |
| `Effects_SpinningLED(pos, color)` | Kroužící LED (stand-by) |
| `Effects_Breathing(step, color)` | Dýchací efekt |
| `Effects_SegmentChase(step, color)` | Běžící segmenty |
| `Effects_KnightRider(pos, color)` | K.I.T.T. efekt s ocasem |
| `Effects_LoadingBar(progress, color)` | Progress bar |
| `Effects_RainbowDigit(digit, show_dp, step)` | Číslice s měnící se rainbow barvou |
| `Effects_RainbowGradientDigit(digit, show_dp, step)` | Číslice s rainbow gradientem |

### Pomocné funkce

```c
WS2815_Color_t Effects_HSV_to_RGB(uint8_t h, uint8_t s, uint8_t v);
```

### Rozdíl mezi rainbow efekty

| Efekt | Popis |
|---|---|
| `Effects_RainbowDigit` | Celá číslice svítí jednou barvou, barva se mění v čase |
| `Effects_RainbowGradientDigit` | Každá LED má jinou barvu z duhy (gradient), gradient se pohybuje |

## Použití

### Příklad 1: Základní použití

```c
#include "sw_ws2815.h"

void app_main(void) {
    WS2815_Init();
    WS2815_SetBrightness(50);

    WS2815_Color_t green = {0, 255, 0};

    // Zobrazení číslice "8" s desetinnou tečkou
    WS2815_DisplayDigit(8, green, 1);
    WS2815_Update();
    while(WS2815_IsBusy());
}
```

### Příklad 2: Rainbow animace

```c
#include "sw_ws2815.h"
#include "sw_effects.h"

void rainbow_animation(void) {
    Effects_Init();

    while(1) {
        for(uint16_t step = 0; step < 256; step++) {
            Effects_Rainbow(step);
            WS2815_Update();
            while(WS2815_IsBusy());
            HAL_Delay(20);
        }
    }
}
```

### Příklad 3: Rainbow gradient na číslici

```c
void rainbow_digit_animation(void) {
    while(1) {
        for(uint16_t step = 0; step < 256; step++) {
            Effects_RainbowGradientDigit(8, 1, step);
            WS2815_Update();
            while(WS2815_IsBusy());
            HAL_Delay(10);
        }
    }
}
```

## Mapování segmentů

```
    aaaa        Segment a: LED 0-3
   f    b       Segment b: LED 4-7
   f    b       Segment c: LED 8-11
    gggg        Segment d: LED 12-15
   e    c       Segment e: LED 16-19
   e    c       Segment f: LED 20-23
    dddd  dp    Segment g: LED 24-27
                Decimal point: LED 28
```

## DMA Buffer struktura

```
DMA buffer obsahuje:
- 29 LED × 24 bitů = 696 slotů pro data
- 250 slotů pro reset periodu (>280µs LOW)
- Celkem: ~1940 bytů
```

## Troubleshooting

### LED se nerozsvěcují

1. **Zkontrolovat napájení:** WS2815 potřebuje 12V
2. **Zkontrolovat zapojení:** Data pin na PA0
3. **Zkontrolovat system clock:** Musí být 64 MHz
4. **Zkontrolovat HAL_TIM_MODULE_ENABLED** v `stm32g0xx_hal_conf.h`

### Špatné barvy

- WS2815 používá GRB pořadí (driver to už řeší)
- Zkontrolovat brightness nastavení (rozsah 10-254)
- Zkontrolovat napájecí napětí (při nízkém napětí špatné barvy)

### Blikání při změně dat

- Příčina: Chyběla explicitní reset perioda v DMA bufferu
- Řešení: Driver obsahuje 250 reset slotů na konci DMA bufferu
- WS2815 potřebuje >280µs LOW signál pro latch dat do LED

### DMA chyby

- Zkontrolovat, že DMA1_Channel1 není použit jinde
- Zkontrolovat interrupt prioritu (0 = nejvyšší)

## Výkonnost

### Timing

- Refresh rate: ~275 Hz pro 29 LED
- Transfer time: ~0.9 ms pro 29 LED (29 × 24 bits × 1.25µs + reset)
- CPU usage: Minimální (používá DMA)

### Paměť

- RAM: ~2 KB (led_buffer + dma_buffer)
- Flash: ~1.5 KB (driver + effects code)

## Reference

- [WS2815 Datasheet](https://cdn-shop.adafruit.com/product-files/2757/WS2815.pdf)
- [STM32G0 Reference Manual](https://www.st.com/resource/en/reference_manual/rm0444-stm32g0x0-advanced-armbased-32bit-mcus-stmicroelectronics.pdf)

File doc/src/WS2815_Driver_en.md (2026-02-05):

# WS2815 LED Driver - Documentation

## Overview

Driver for controlling WS2815 addressable RGB LEDs on STM32G031F8Px platform. The driver uses TIM2 + DMA to generate precise PWM signal compatible with WS2815 protocol.

## Specifications

- **MCU:** STM32G031F8Px (Cortex-M0+)
- **System clock:** 64 MHz
- **LED type:** WS2815 RGB addressable LEDs
- **Communication:** 1-wire, 800 kHz bitrate
- **LED count:** 29 (7 segments × 4 LEDs + 1 decimal point)
- **Color format:** GRB (Green-Red-Blue)

## Hardware Configuration

### Connection

| Signal | MCU Pin | Peripheral | Description |
|---|---|---|---|
| Data | PA0 | TIM2_CH1 | Data signal for WS2815 |
| VCC | - | - | 12V power for LEDs |
| GND | GND | - | Common ground |

### Peripherals

- **TIM2:** Timer for PWM generation
  - Channel 1 (PA0)
  - Frequency: 800 kHz
  - Prescaler: 0
  - Period: 79 (@ 64MHz = 1.25µs)

- **DMA1 Channel 1:** PWM data transfer
  - Request: TIM2_CH1
  - Direction: Memory-to-Peripheral
  - Mode: Normal
  - Priority: High (0)

## WS2815 Timing

WS2815 uses the following timing:

| Bit | T0H | T0L | T1H | T1L | Total  |
|-----|---|---|---|---|---|
| 0 | 375ns  | 875ns | - | - | 1.25µs |
| 1 | - | - | 812.5ns | 437.5ns| 1.25µs |
| RES | - | >280µs  | - | - | - |

### Driver Implementation

```c
#define WS2815_TIM_PERIOD   80    // 1.25µs @ 64MHz
#define WS2815_BIT_0_DUTY   24    // 375ns (30% duty)
#define WS2815_BIT_1_DUTY   52    // 812.5ns (65% duty)
#define WS2815_RESET_SLOTS  250   // >280µs reset period
```

## File Structure

```
LED7SEG02/sw/
├── sw/
│   ├── sw_ws2815.c       # Driver implementation
│   └── sw_ws2815.h       # Public API
├── sw_effects/
│   ├── sw_effects.c      # Effects library
│   └── sw_effects.h
├── Core/
│   └── Src/
│       └── stm32g0xx_it.c  # DMA interrupt handler
└── src/
    └── app.c             # Application code
```

## API Reference

### Data Types

```c
typedef struct {
    uint8_t r;  // Red (0-255)
    uint8_t g;  // Green (0-255)
    uint8_t b;  // Blue (0-255)
} WS2815_Color_t;
```

### Functions

#### WS2815_Init()

```c
void WS2815_Init(void);
```

Initializes WS2815 driver (GPIO, TIM2, DMA).

---

#### WS2815_SetLED()

```c
void WS2815_SetLED(uint8_t index, WS2815_Color_t color);
```

Sets color of single LED in buffer.

**Parameters:**
- `index`: LED index (0-28)
- `color`: RGB color

**Note:** Change takes effect after calling `WS2815_Update()`

---

#### WS2815_SetSegment()

```c
void WS2815_SetSegment(uint8_t segment, WS2815_Color_t color);
```

Sets color of entire segment (4 LEDs).

**Parameters:**
- `segment`: Segment index (0-7)
- `color`: RGB color

---

#### WS2815_DisplayDigit()

```c
void WS2815_DisplayDigit(uint8_t digit, WS2815_Color_t color, uint8_t show_dp);
```

Displays digit 0-9 on display.

**Parameters:**
- `digit`: Digit (0-9)
- `color`: RGB color
- `show_dp`: 1 = show decimal point

---

#### WS2815_Update()

```c
void WS2815_Update(void);
```

Sends buffer to LED strip via DMA.

**Note:** Function is non-blocking, uses DMA transfer

---

#### WS2815_Clear()

```c
void WS2815_Clear(void);
```

Turns off all LEDs (sets to black).

---

#### WS2815_SetBrightness()

```c
void WS2815_SetBrightness(uint8_t brightness);
```

Sets global brightness of all LEDs.

**Parameters:**
- `brightness`: 0 (off), 10-254 (functional range)

**Notes:**
- Values 1-9 are automatically set to 10
- Values > 254 are automatically set to 254

---

#### WS2815_IsBusy()

```c
uint8_t WS2815_IsBusy(void);
```

Checks if DMA transfer is in progress.

**Return:** 1 if busy, 0 if ready

## Effects Library (sw_effects)

### Available Effects

| Function | Description |
|---|---|
| `Effects_Rainbow(step)` | Rainbow cycle on all LEDs |
| `Effects_SpinningLED(pos, color)` | Spinning LED (stand-by) |
| `Effects_Breathing(step, color)` | Breathing effect |
| `Effects_SegmentChase(step, color)` | Running segments |
| `Effects_KnightRider(pos, color)` | K.I.T.T. effect with tail |
| `Effects_LoadingBar(progress, color)` | Progress bar |
| `Effects_RainbowDigit(digit, show_dp, step)` | Digit with changing rainbow color |
| `Effects_RainbowGradientDigit(digit, show_dp, step)` | Digit with rainbow gradient |

### Helper Functions

```c
WS2815_Color_t Effects_HSV_to_RGB(uint8_t h, uint8_t s, uint8_t v);
```

### Difference Between Rainbow Effects

| Effect | Description |
|---|---|
| `Effects_RainbowDigit` | Entire digit lights with one color, color changes over time |
| `Effects_RainbowGradientDigit` | Each LED has different rainbow color (gradient), gradient moves |

## Usage

### Example 1: Basic Usage

```c
#include "sw_ws2815.h"

void app_main(void) {
    WS2815_Init();
    WS2815_SetBrightness(50);

    WS2815_Color_t green = {0, 255, 0};

    // Display digit "8" with decimal point
    WS2815_DisplayDigit(8, green, 1);
    WS2815_Update();
    while(WS2815_IsBusy());
}
```

### Example 2: Rainbow Animation

```c
#include "sw_ws2815.h"
#include "sw_effects.h"

void rainbow_animation(void) {
    Effects_Init();

    while(1) {
        for(uint16_t step = 0; step < 256; step++) {
            Effects_Rainbow(step);
            WS2815_Update();
            while(WS2815_IsBusy());
            HAL_Delay(20);
        }
    }
}
```

### Example 3: Rainbow Gradient on Digit

```c
void rainbow_digit_animation(void) {
    while(1) {
        for(uint16_t step = 0; step < 256; step++) {
            Effects_RainbowGradientDigit(8, 1, step);
            WS2815_Update();
            while(WS2815_IsBusy());
            HAL_Delay(10);
        }
    }
}
```

## Segment Mapping

```
    aaaa        Segment a: LED 0-3
   f    b       Segment b: LED 4-7
   f    b       Segment c: LED 8-11
    gggg        Segment d: LED 12-15
   e    c       Segment e: LED 16-19
   e    c       Segment f: LED 20-23
    dddd  dp    Segment g: LED 24-27
                Decimal point: LED 28
```

## DMA Buffer Structure

```
DMA buffer contains:
- 29 LEDs × 24 bits = 696 slots for data
- 250 slots for reset period (>280µs LOW)
- Total: ~1940 bytes
```

## Troubleshooting

### LEDs not lighting

1. **Check power supply:** WS2815 needs 12V
2. **Check wiring:** Data pin on PA0
3. **Check system clock:** Must be 64 MHz
4. **Check HAL_TIM_MODULE_ENABLED** in `stm32g0xx_hal_conf.h`

### Wrong colors

- WS2815 uses GRB order (driver handles this)
- Check brightness setting (range 10-254)
- Check power supply voltage (low voltage causes color issues)

### Flickering when changing data

- Cause: Missing explicit reset period in DMA buffer
- Solution: Driver includes 250 reset slots at end of DMA buffer
- WS2815 needs >280µs LOW signal to latch data to LEDs

### DMA errors

- Check that DMA1_Channel1 is not used elsewhere
- Check interrupt priority (0 = highest)

## Performance

### Timing

- Refresh rate: ~275 Hz for 29 LEDs
- Transfer time: ~0.9 ms for 29 LEDs (29 × 24 bits × 1.25µs + reset)
- CPU usage: Minimal (uses DMA)

### Memory

- RAM: ~2 KB (led_buffer + dma_buffer)
- Flash: ~1.5 KB (driver + effects code)

## References

- [WS2815 Datasheet](https://cdn-shop.adafruit.com/product-files/2757/WS2815.pdf)
- [STM32G0 Reference Manual](https://www.st.com/resource/en/reference_manual/rm0444-stm32g0x0-advanced-armbased-32bit-mcus-stmicroelectronics.pdf)

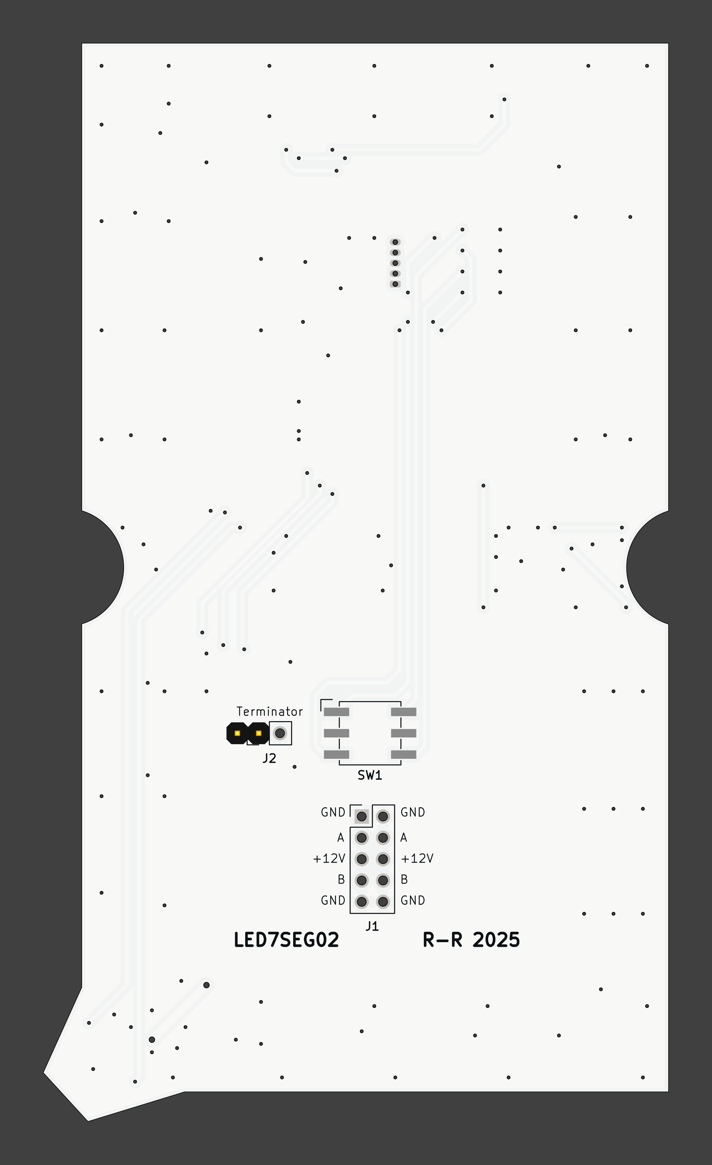
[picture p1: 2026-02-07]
doc/gen/img/LED7SEG02-bottom.png

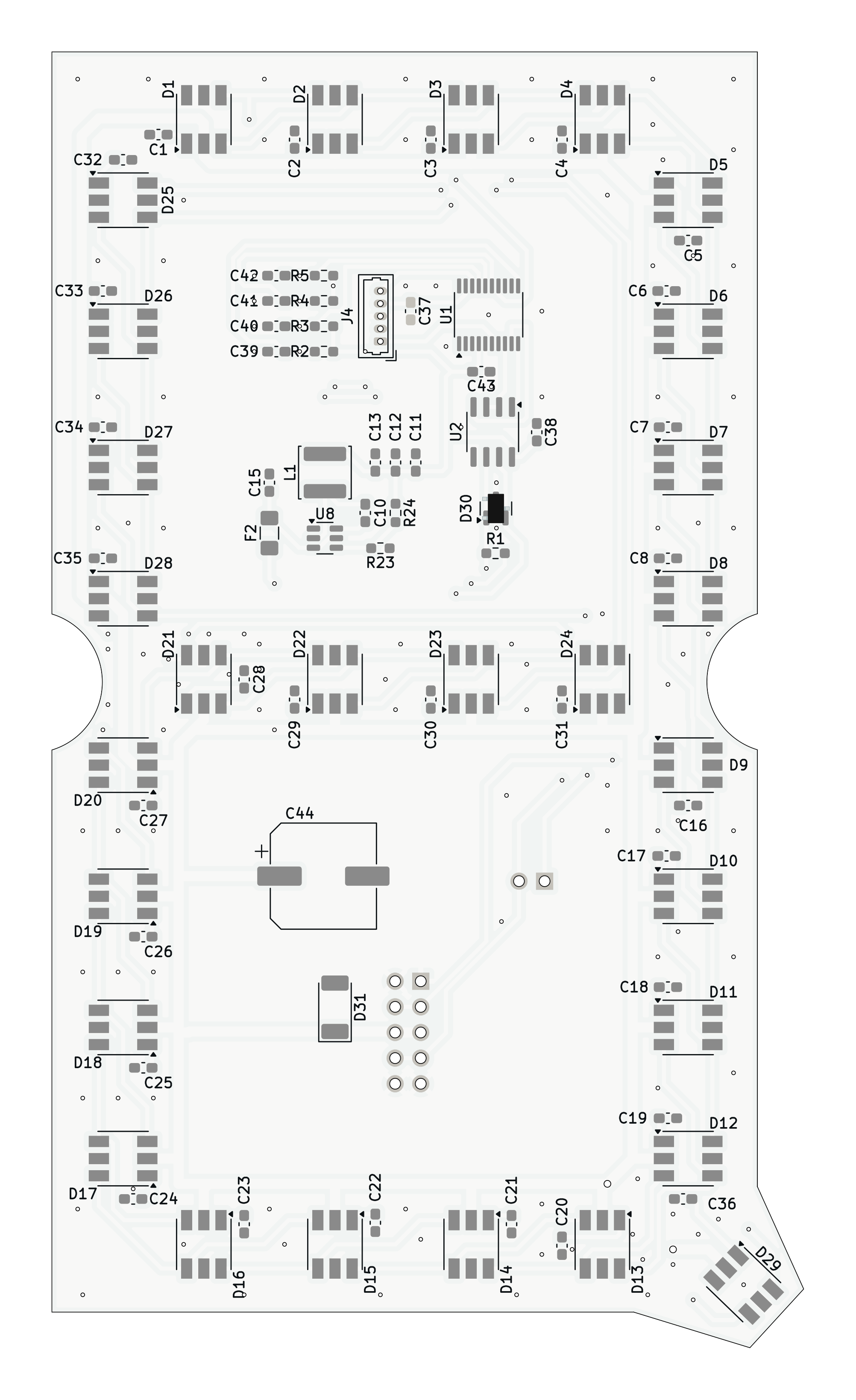
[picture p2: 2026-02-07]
doc/gen/img/LED7SEG02-top.png

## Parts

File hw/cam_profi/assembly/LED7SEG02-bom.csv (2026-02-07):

Component | Description | Part | References | Value | Footprint | Quantity Per PCB | Datasheet | sim.device | sim.pins
1 | Unpolarized capacitor | C | C1C2C3C4C5C6C7C8C10C13C16C17C18C19C20C21C22C23C24C25C26C27C28C29C30C31C32C33C34C35C36C38C39C40C41C42C43 | 100nF | C_0603_1608Metric_Pad1.08x0.95mm_HandSolder | 37 | ~
2 | Unpolarized capacitor | C | C15 | 2,2uF/35 | C_0603_1608Metric_Pad1.08x0.95mm_HandSolder | 1 | ~
3 | Polarized capacitor | C_Polarized | C44 | 470uF/25V | CP_Elec_10x12.6 | 1 | ~
4 | Unpolarized capacitor | C | C11C12 | CL10X106MO8NRNC | C_0603_1608Metric_Pad1.08x0.95mm_HandSolder | 2 | ~
5 | 50V 1A General Purpose Rectifier Diode, MELF | SM4001 | D31 | SM4001 | D_MELF | 1 | http://cdn-reichelt.de/documents/datenblatt/A400/SMD1N400%23DIO.pdf | D | 1=K 2=A
6 | 7V/12V, 600W Asymmetrical TVS Diode Array, SOT-23 | SM712_SOT23 | D30 | SM712_SOT23 | SOT-23 | 1 | https://www.littelfuse.com/~/media/electronics/datasheets/tvs_diode_arrays/littelfuse_tvs_diode_array_sm712_datasheet.pdf.pdf
7 |  | WS2815 | D1D2D3D4D5D6D7D8D9D10D11D12D13D14D15D16D17D18D19D20D21D22D23D24D25D26D27D28D29 | WS2815 | LED_RGB_5050-6 | 29 | https://www.tme.eu/Document/81275cf5ca3bcaa498439ec9fda98288/WS2815B-V1.pdf
8 | Fuse | Fuse | F2 | Fuse | Fuse_1206_3216Metric_Pad1.42x1.75mm_HandSolder | 1 | ~
9 | Generic connector, single row, 01x02, script generated (kicad-library-utils/schlib/autogen/connector/) | Conn_01x02 | J2 | Conn_01x02 | PinHeader_1x02_P2.54mm_Vertical | 1 | ~
10 | Generic connector, double row, 02x05, odd/even pin numbering scheme (row 1 odd numbers, row 2 even numbers), script generated (kicad-library-utils/schlib/autogen/connector/) | Conn_02x05_Odd_Even | J1 | Conn_02x05_Odd_Even | PinHeader_2x05_P2.54mm_Vertical | 1 | ~
11 | Generic connector, single row, 01x05, script generated (kicad-library-utils/schlib/autogen/connector/) | Conn_01x05 | J4 | DBG | Molex_PicoBlade_53047-0510_1x05_P1.25mm_Vertical | 1 | ~
12 | Inductor with ferrite core | L_Ferrite | L1 | LQH5BPN4R7NT0L | L_APV_ANR5020 | 1 | ~
13 | Resistor, small symbol | R_Small | R1 | 120R | R_0603_1608Metric_Pad0.98x0.95mm_HandSolder | 1 | ~
14 | Resistor | R | R2R3R4R5 | 10K | R_0603_1608Metric_Pad0.98x0.95mm_HandSolder | 4 | ~
15 | Resistor | R | R23 | 22.1K | R_0603_1608Metric_Pad0.98x0.95mm_HandSolder | 1 | ~
16 | Resistor | R | R24 | 100K | R_0603_1608Metric_Pad0.98x0.95mm_HandSolder | 1 | ~
17 | Rotary switch, 4-bit encoding, 10 positions, Real code | SW_Coded_SH-7010 | SW1 | MSSR-16S-TR | Nidec_Copal_SH-7010B | 1 | https://www.nidec-copal-electronics.com/e/catalog/switch/sh-7000.pdf
18 | 4.5-V to 36-V, 3-A synchronous buck converter with 40-µA IQ, SOT-23-6 | LMR51430 | U8 | LMR51430 | SOT-23-6 | 1 | https://www.ti.com/lit/ds/symlink/lmr51430.pdf
19 | True RS-485/RS-422, 10Mbps, Slew-Rate Limited, with low-power shutdown, with receiver/driver enable, 32 receiver drive capacitity, DIP-8 and SOIC-8 | MAX3485 | U2 | MAX3485 | SOIC-8_3.9x4.9mm_P1.27mm | 1 | https://datasheets.maximintegrated.com/en/ds/MAX3483-MAX3491.pdf
20 | STMicroelectronics Arm Cortex-M0+ MCU, 64KB flash, 8KB RAM, 64 MHz, 1.7-3.6V, 18 GPIO, TSSOP20 | STM32G031F8Px | U1 | STM32G031F8Px | TSSOP-20_4.4x6.5mm_P0.65mm | 1 | https://www.st.com/resource/en/datasheet/stm32g031f8.pdf

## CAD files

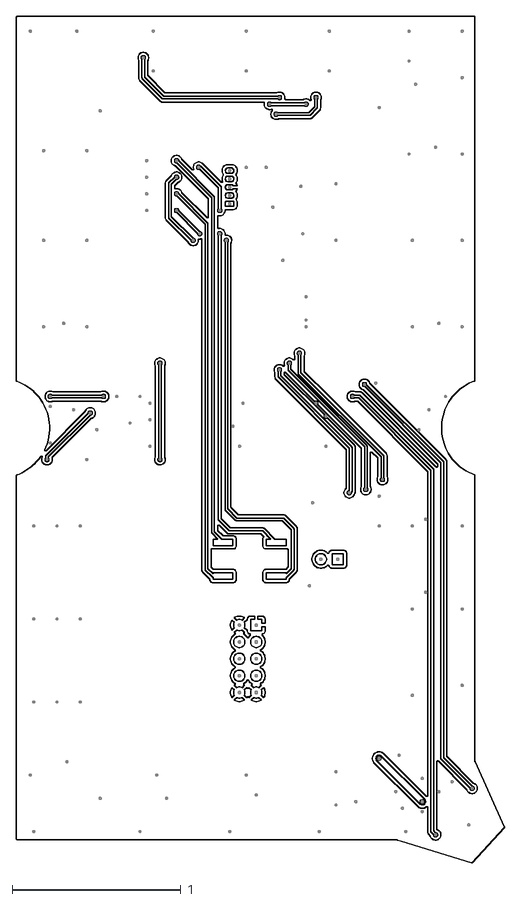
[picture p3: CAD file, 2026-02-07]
doc/gen/dxf/LED7SEG02-B_Cu.dxf
2.89 x 5.02

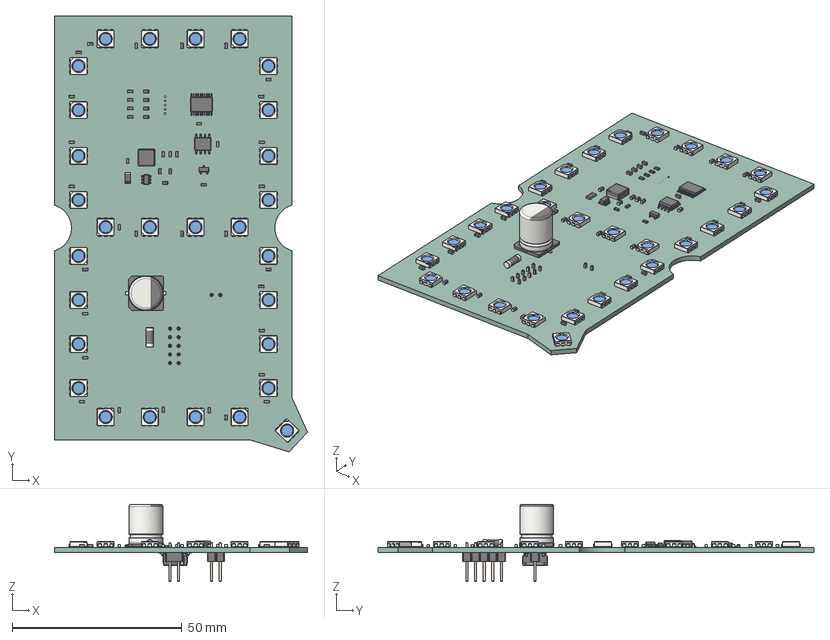
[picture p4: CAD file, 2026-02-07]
doc/gen/LED7SEG02.step
74.6 x 128.5 x 22.8 mm
LED_RGB_5050-6 x 29
C_0603_1608Metric x 40
SOT-23-6
D_MELF
L_APV_ANR5020
R_0603_1608Metric x 7
CP_Elec_10x12.6
SOIC-8_3.9x4.9mm_P1.27mm
SOT-23
Fuse_1206_3216Metric
TSSOP-20_4.4x6.5mm_P0.65mm
PinHeader_1x02_P2.54mm_Vertical
Nidec_Copal_SH-7010B
PinHeader_2x05_P2.54mm_Vertical
kibot_671h37fa_PCB

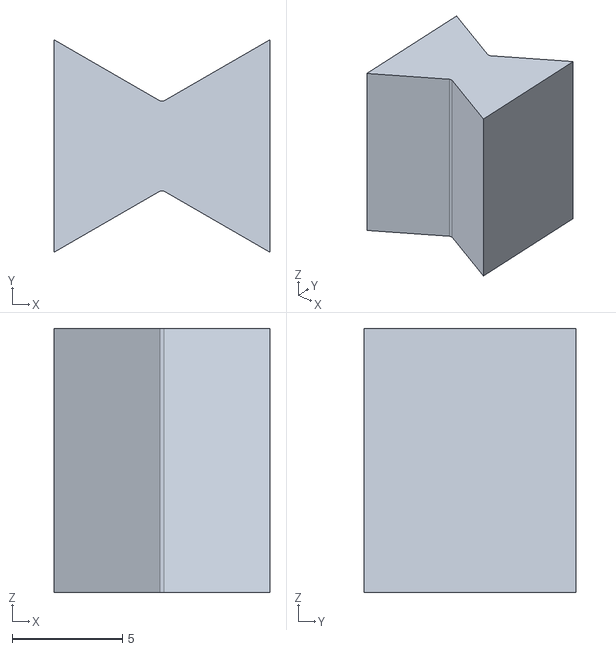
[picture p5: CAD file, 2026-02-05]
hw/3d_print/LED7SEG02_Joint.stl
9.80 x 9.65 x 12.0

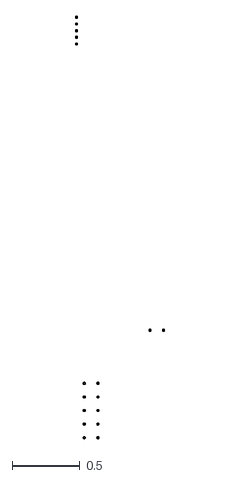
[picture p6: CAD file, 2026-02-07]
doc/gen/dxf/LED7SEG02-User_Eco2.dxf
0.655 x 3.11

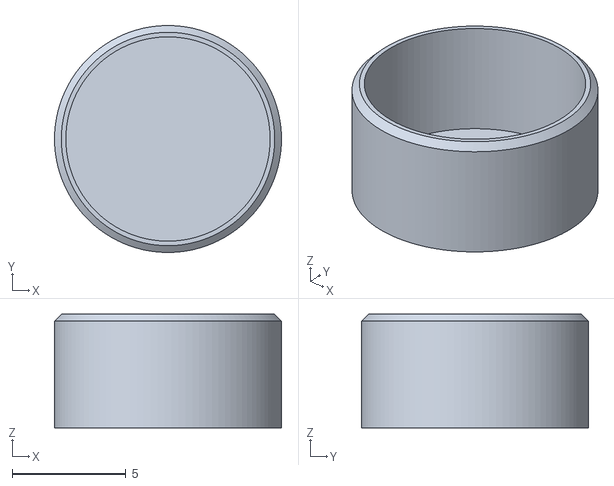
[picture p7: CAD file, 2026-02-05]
hw/3d_print/LED7SEG02_GlassC.stl
10.0 x 10.00 x 5.00

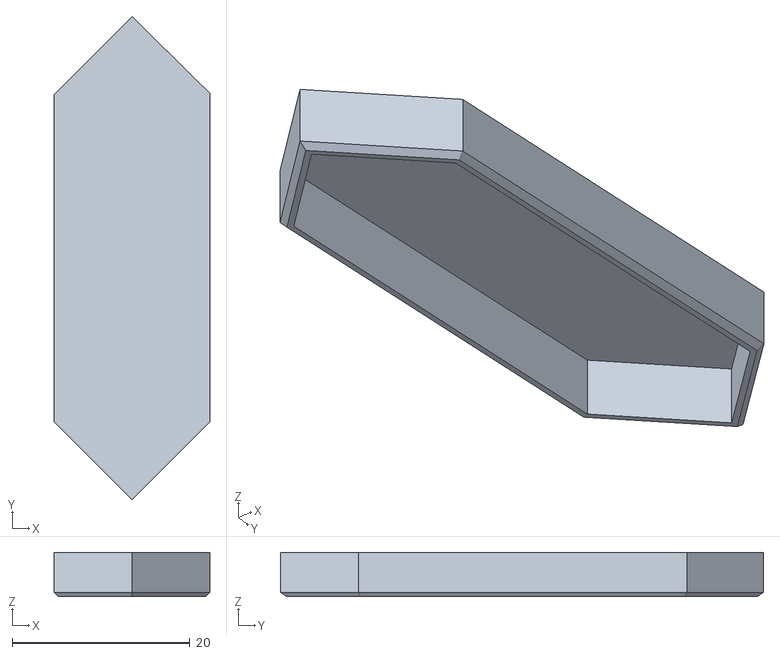
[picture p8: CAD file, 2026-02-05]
hw/3d_print/LED7SEG02_GlassR.stl
17.5 x 54.3 x 5.00

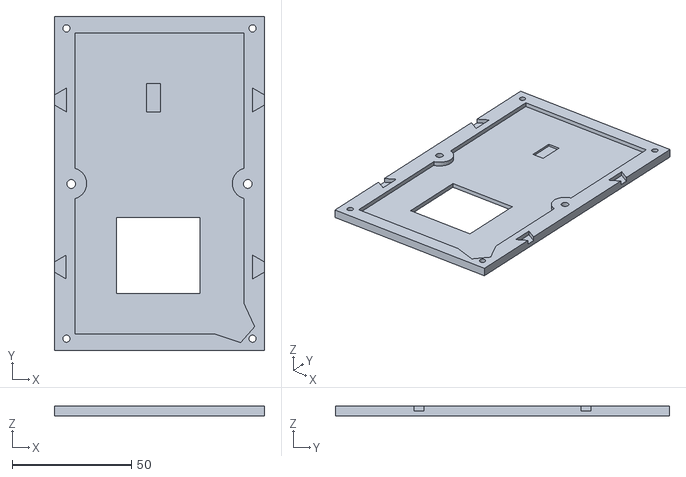
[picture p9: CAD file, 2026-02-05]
hw/3d_print/LED7SEG02_Cover.stl
88.0 x 140.0 x 4.00

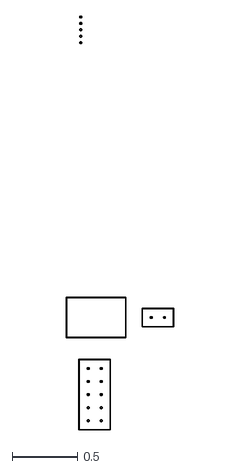
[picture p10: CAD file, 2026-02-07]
doc/gen/dxf/LED7SEG02-B_Courtyard.dxf
0.821 x 3.17

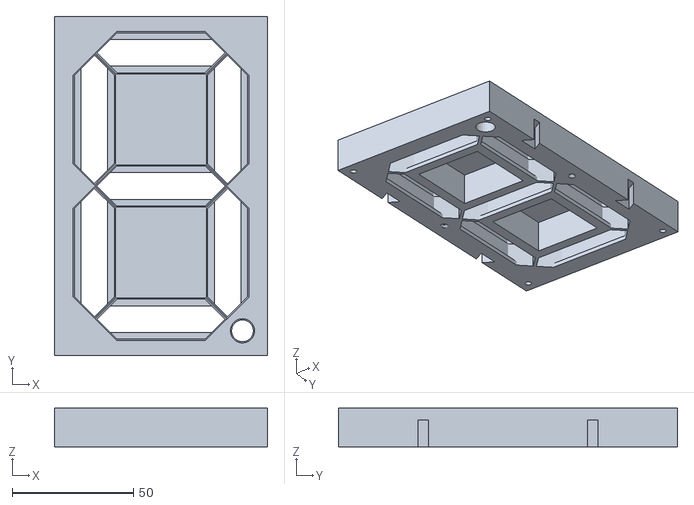
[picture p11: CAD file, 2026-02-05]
hw/3d_print/LED7SEG02_Body.stl
88.0 x 140.0 x 16.0

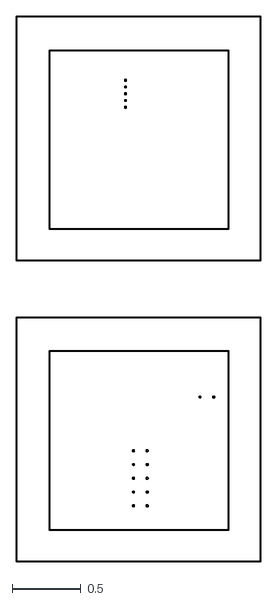
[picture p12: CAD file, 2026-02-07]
doc/gen/dxf/LED7SEG02-User_4.dxf
1.78 x 3.96

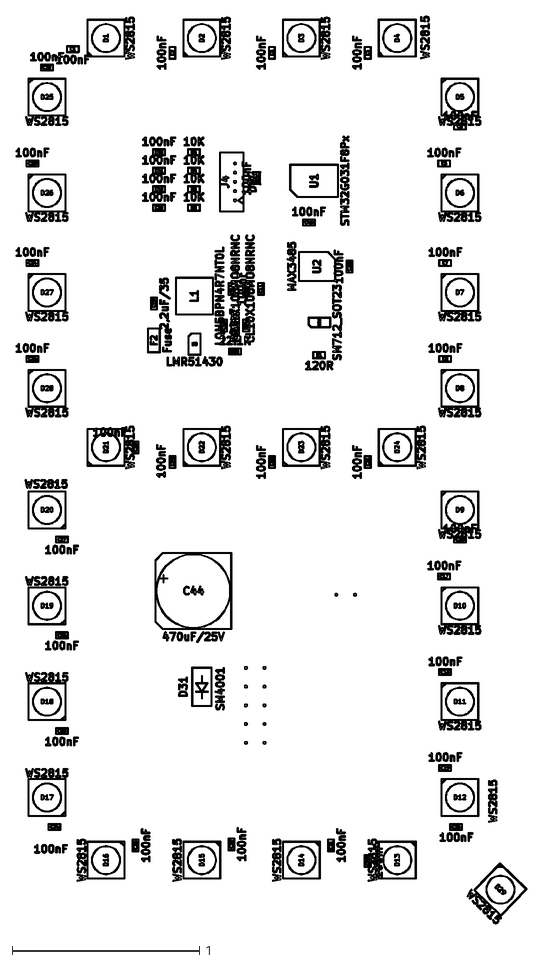
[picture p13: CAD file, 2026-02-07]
doc/gen/dxf/LED7SEG02-F_Fab.dxf
2.73 x 4.84

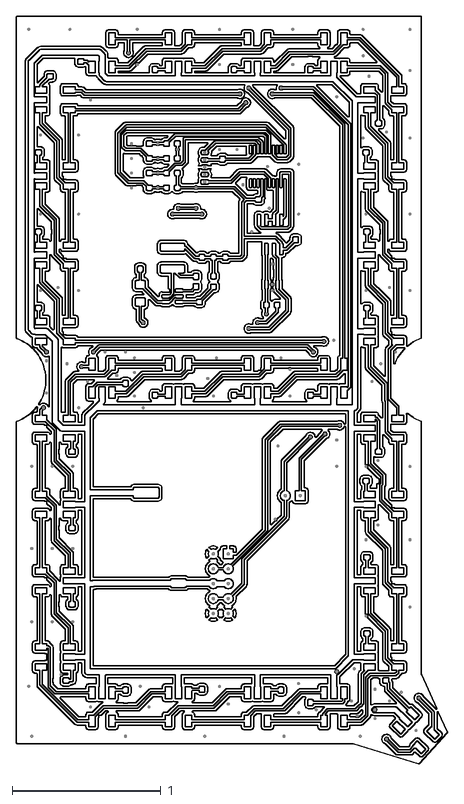
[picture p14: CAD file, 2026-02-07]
doc/gen/dxf/LED7SEG02-F_Cu.dxf
2.89 x 5.02

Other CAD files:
doc/gen/dxf/LED7SEG02-B_Adhesive.dxf
doc/gen/dxf/LED7SEG02-B_Fab.dxf
doc/gen/dxf/LED7SEG02-B_Mask.dxf
doc/gen/dxf/LED7SEG02-B_Paste.dxf
doc/gen/dxf/LED7SEG02-B_Silkscreen.dxf
doc/gen/dxf/LED7SEG02-Edge_Cuts.dxf
doc/gen/dxf/LED7SEG02-F_Adhesive.dxf
doc/gen/dxf/LED7SEG02-F_Courtyard.dxf
doc/gen/dxf/LED7SEG02-F_Mask.dxf
doc/gen/dxf/LED7SEG02-F_Paste.dxf
doc/gen/dxf/LED7SEG02-F_Silkscreen.dxf

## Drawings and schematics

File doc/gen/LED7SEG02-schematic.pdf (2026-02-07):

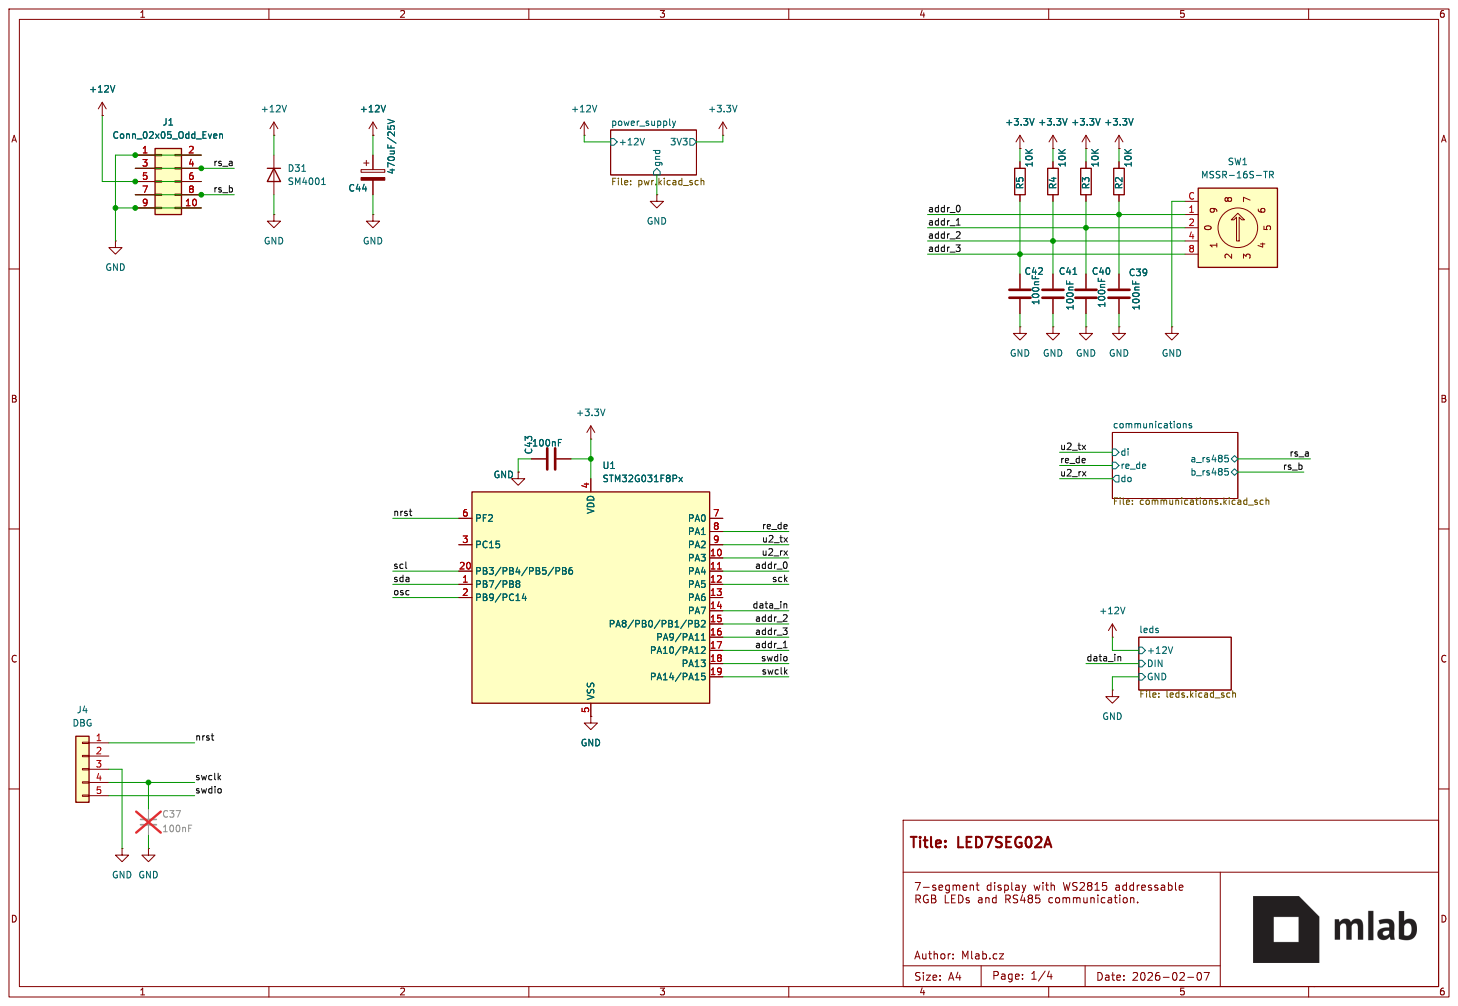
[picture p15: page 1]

communications File: communications.kicad_sch +12V gnd

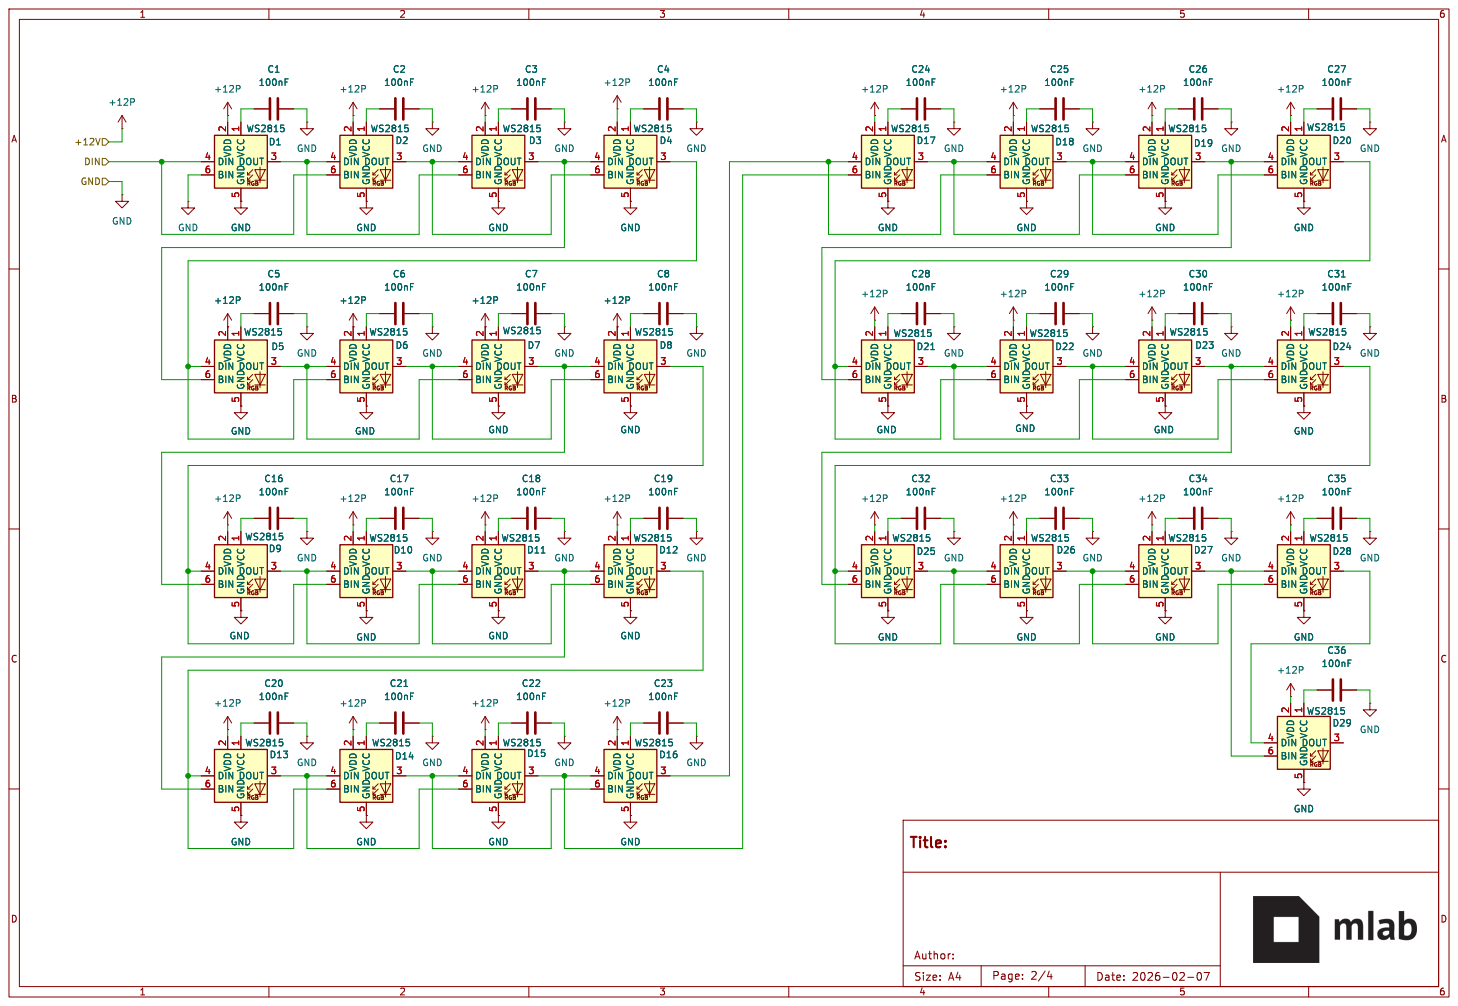
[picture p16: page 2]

5 DOUT 3D20 WS2815 GND GND GND

5 DOUT 3 D13 WS2815 DIN 4 BIN 6 VDD

5 DOUT 3 +12P D7 WS2815 DIN 4 BIN 6 VDD

5 DOUT 3 D6 WS2815 DIN 4 BIN 6 VDD

5 DOUT 3 D22 WS2815 DIN 4 BIN 6 VDD

5 DOUT 3 D23 WS2815 DIN 4 BIN 6 VDD

5 DOUT 3 D29 WS2815 DIN 4 BIN 6 VDD

5 DOUT 3 D10 WS2815 DIN 4 BIN 6 VDD

5 DOUT 3 D11 WS2815 DIN 4 BIN 6 VDD

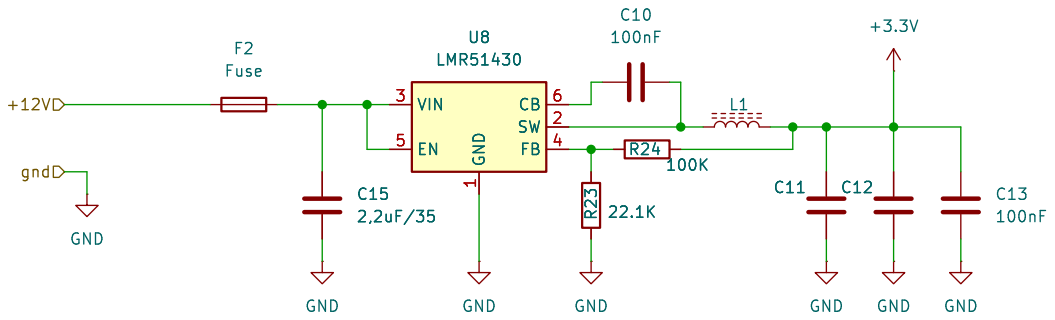
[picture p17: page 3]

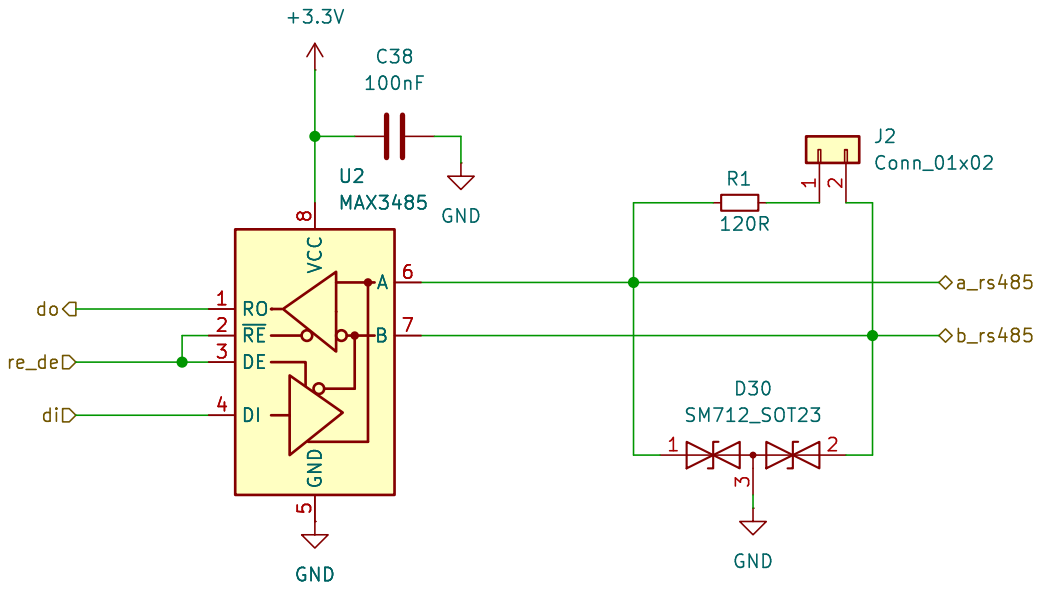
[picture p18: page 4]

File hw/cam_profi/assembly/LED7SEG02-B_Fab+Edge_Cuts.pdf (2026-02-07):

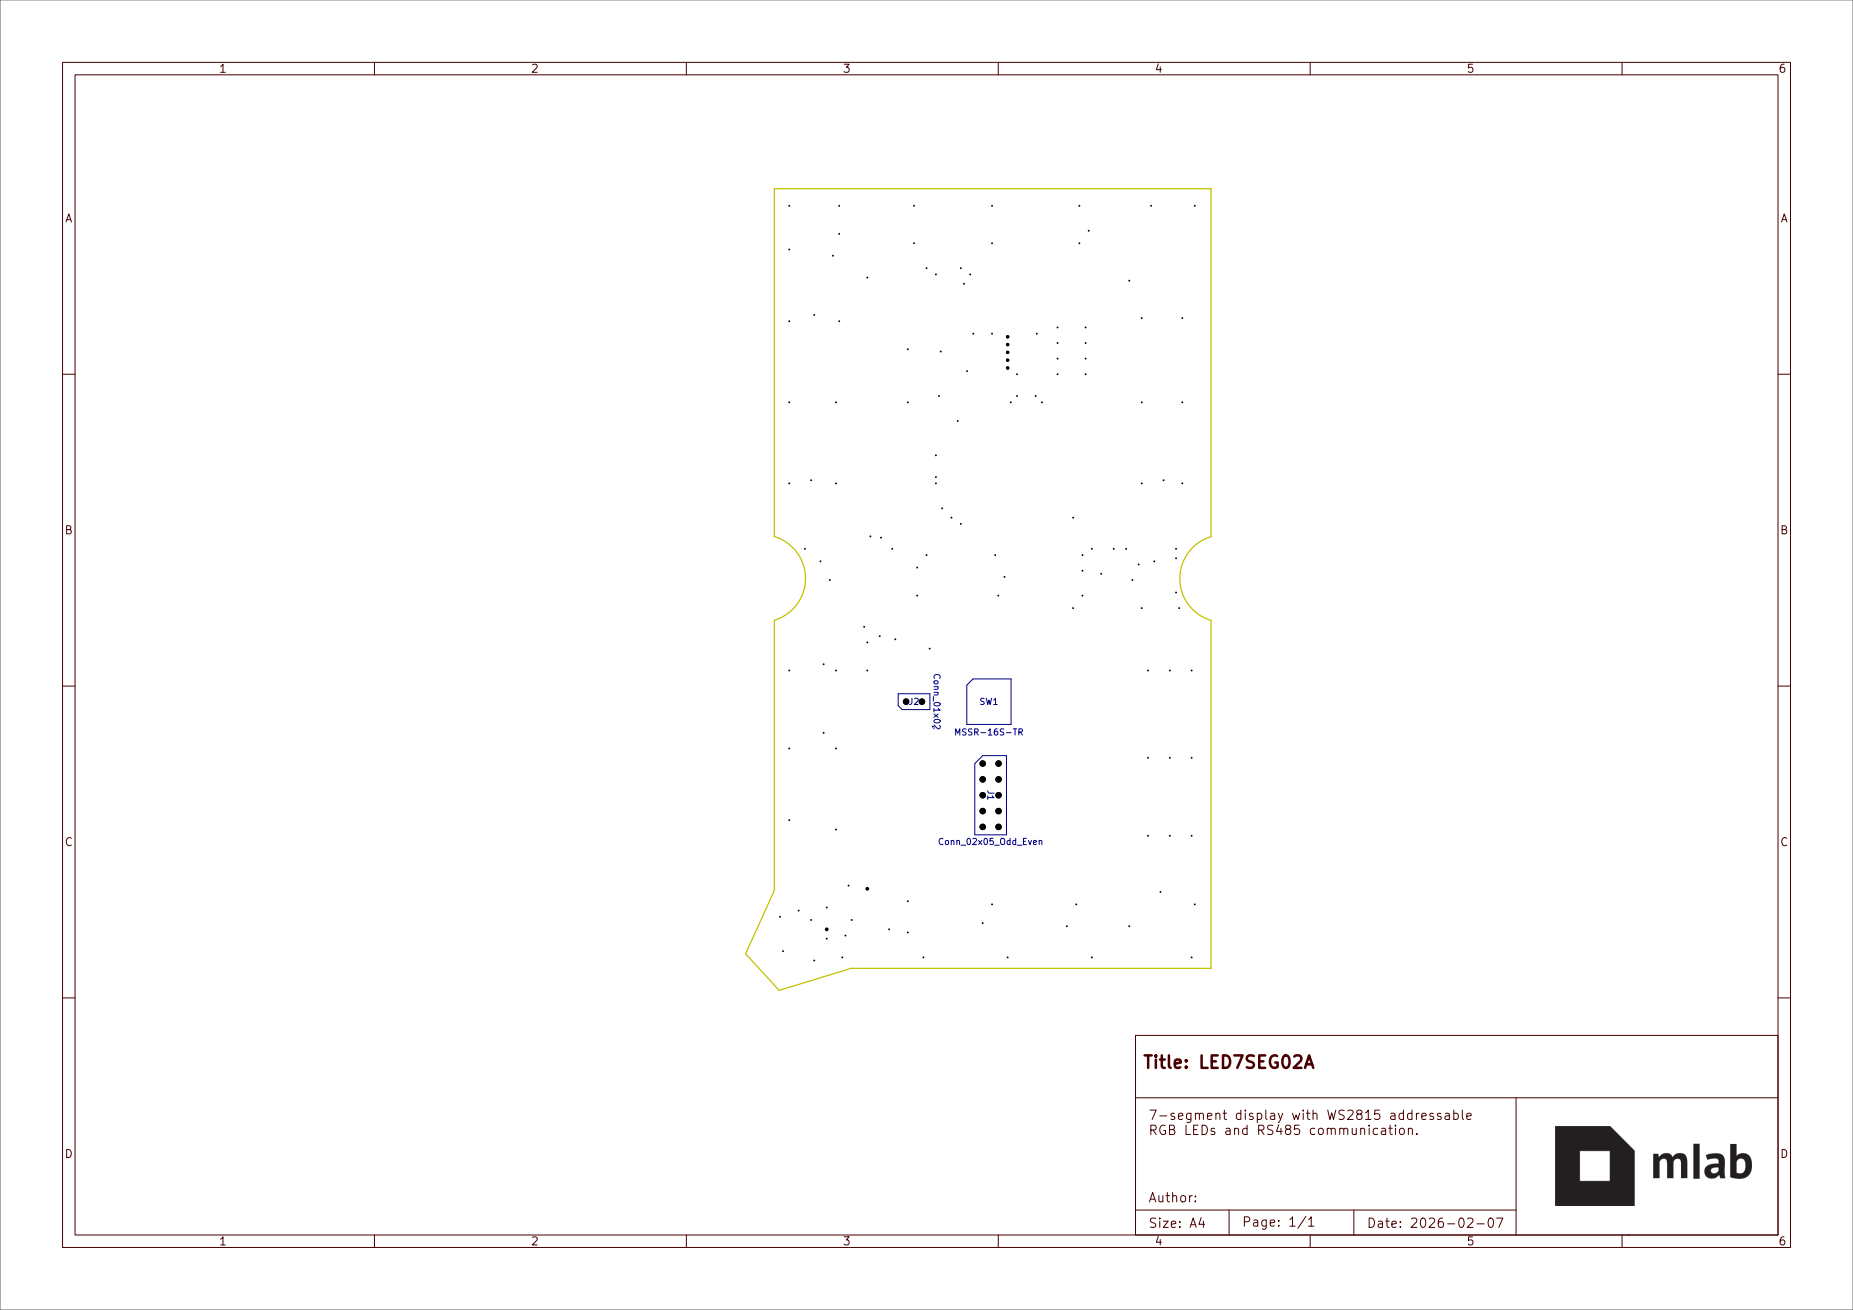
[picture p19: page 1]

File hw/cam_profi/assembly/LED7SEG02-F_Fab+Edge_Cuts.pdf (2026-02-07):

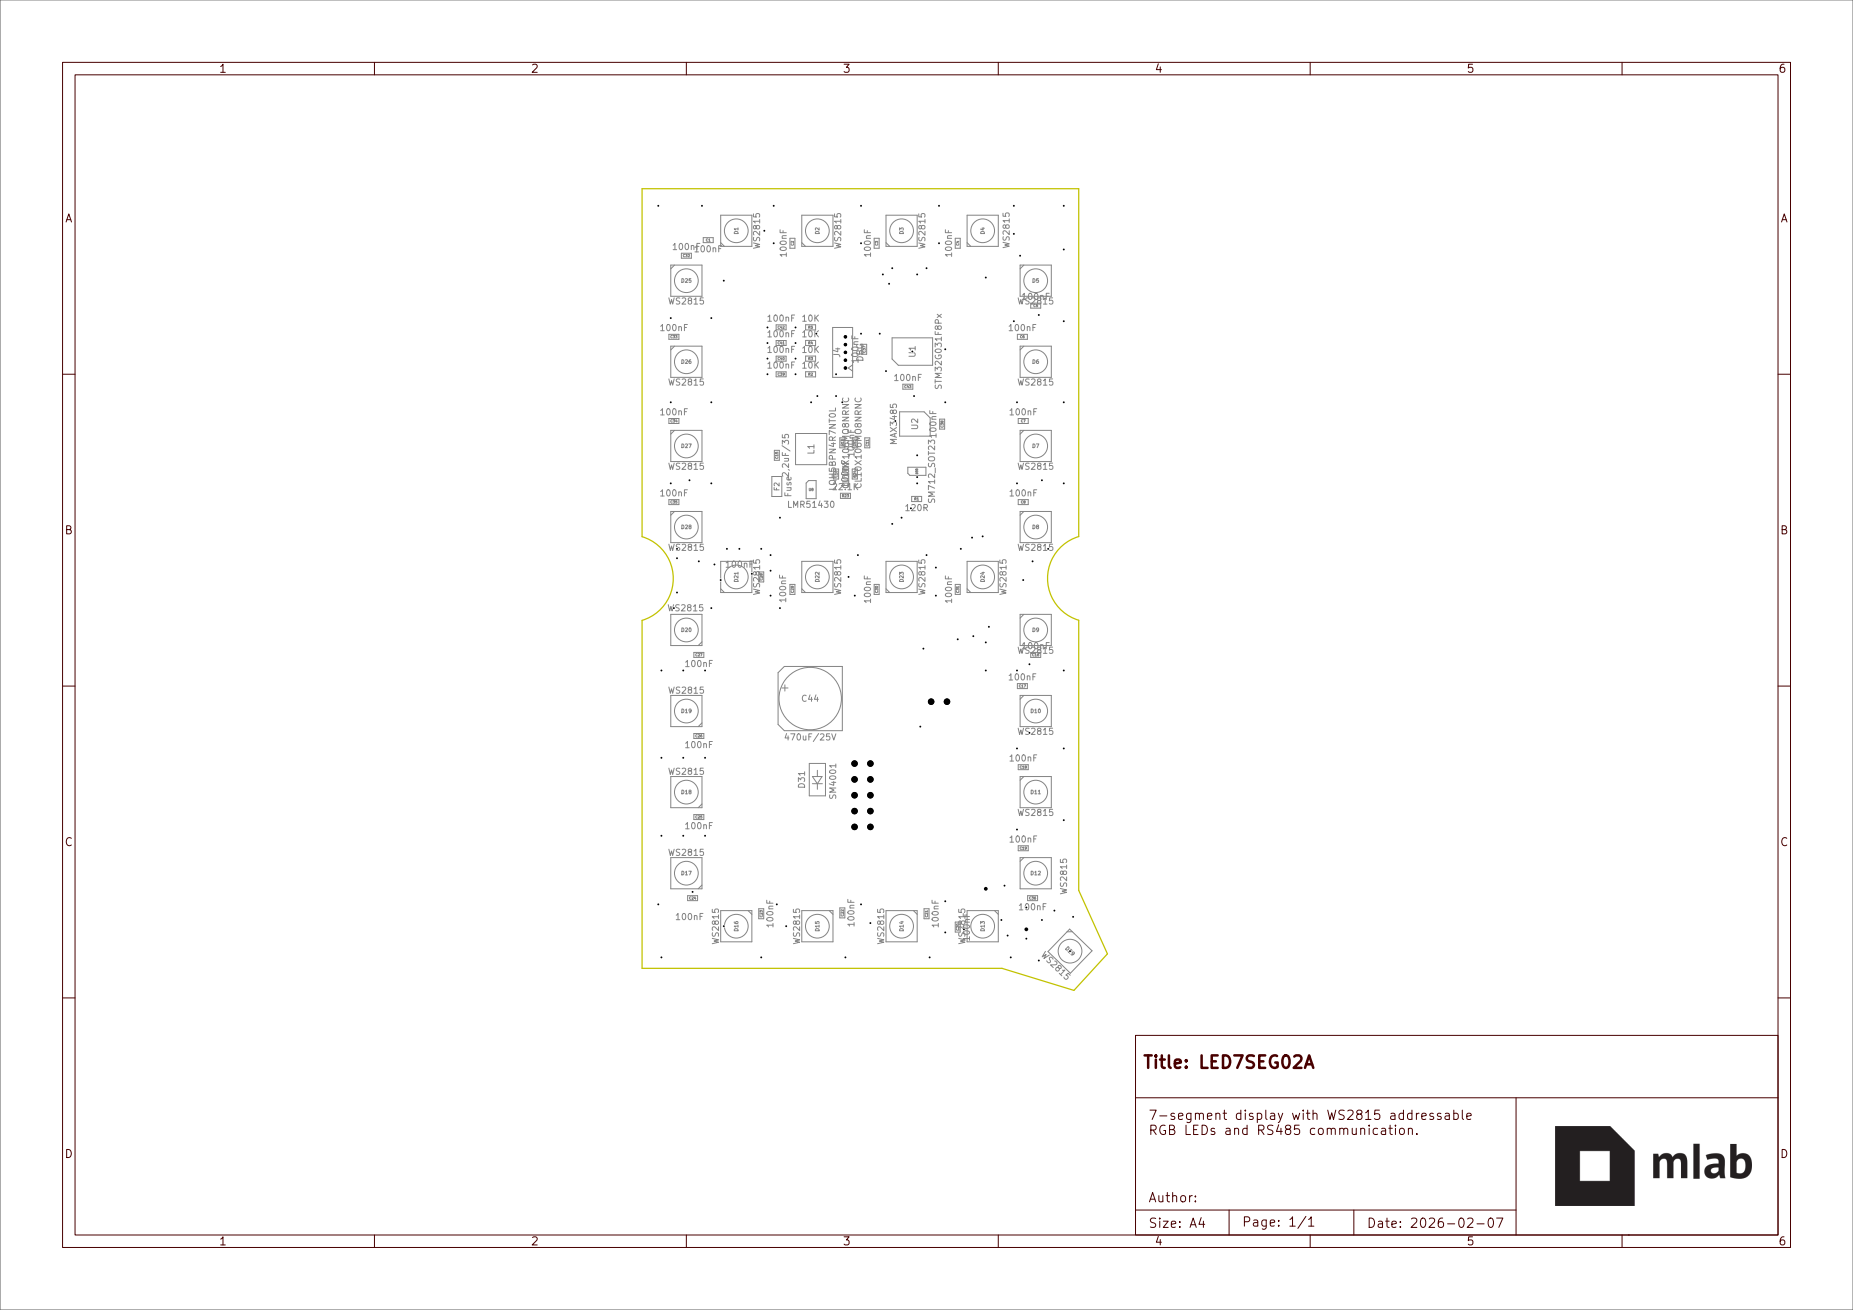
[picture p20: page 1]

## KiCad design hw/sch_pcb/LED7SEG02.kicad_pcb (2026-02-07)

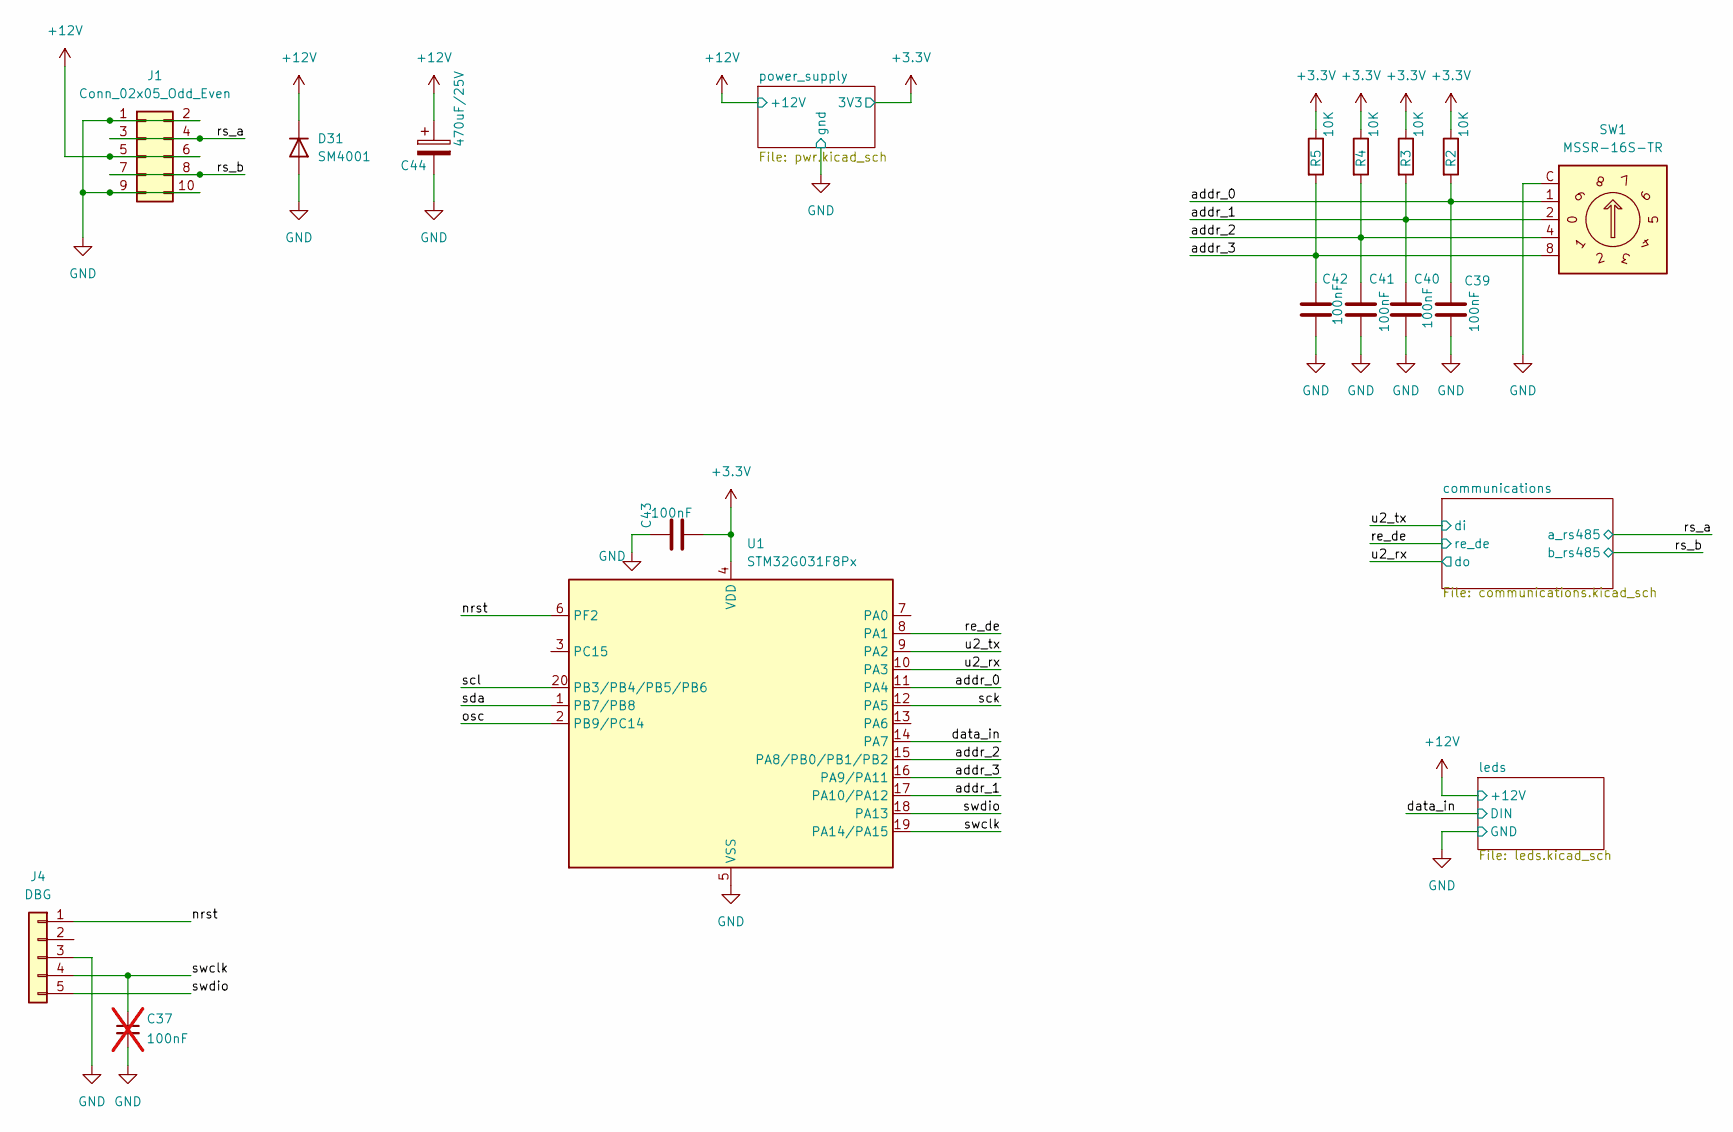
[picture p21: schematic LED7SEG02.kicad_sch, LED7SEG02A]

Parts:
C37: 100nF; C_0603_1608Metric_Pad1.08x0.95mm_HandSolder; not fitted
C39, C40, C41, C42, C43: 100nF; C_0603_1608Metric_Pad1.08x0.95mm_HandSolder
C44: 470uF/25V; CP_Elec_10x12.6
D31: SM4001; D_MELF
J1: Conn_02x05_Odd_Even; PinHeader_2x05_P2.54mm_Vertical
J4: DBG; Molex_PicoBlade_53047-0510_1x05_P1.25mm_Vertical
R2, R3, R4, R5: 10K; R_0603_1608Metric_Pad0.98x0.95mm_HandSolder
SW1: MSSR-16S-TR; Nidec_Copal_SH-7010B
U1: STM32G031F8Px; TSSOP-20_4.4x6.5mm_P0.65mm

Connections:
+3.3V: C43.2, R2.1, R3.1, R4.1, R5.1, U1.4 (VDD); also elsewhere on the board
+12V: C44.1, D31.1 (K), J1.5, J1.6; also elsewhere on the board
/addr_0: C39.1, R2.2, SW1.1, U1.11 (PA4)
/addr_1: C40.1, R3.2, SW1.2, U1.17 (PA10/PA12)
/addr_2: C41.1, R4.2, SW1.4, U1.15 (PA8/PB0/PB1/PB2)
/addr_3: C42.1, R5.2, SW1.8, U1.16 (PA9/PA11)
/data_in: U1.14 (PA7); also elsewhere on the board
/nrst: J4.1, U1.6 (PF2)
/osc: U1.2 (PB9/PC14)
/re_de: U1.8 (PA1); also elsewhere on the board
/rs_a: J1.3, J1.4; also elsewhere on the board
/rs_b: J1.7, J1.8; also elsewhere on the board
/sck: U1.12 (PA5)
/scl: U1.20 (PB3/PB4/PB5/PB6)
/sda: U1.1 (PB7/PB8)
/swclk: C37.1, J4.4, U1.19 (PA14/PA15)
/swdio: J4.5, U1.18 (PA13)
/u2_rx: U1.10 (PA3); also elsewhere on the board
/u2_tx: U1.9 (PA2); also elsewhere on the board
GND: C37.2, C39.2, C40.2, C41.2, C42.2, C43.1, C44.2, D31.2 (A), J1.1, J1.2, J1.9, J1.10, J4.3, SW1.C, U1.5 (VSS); also elsewhere on the board

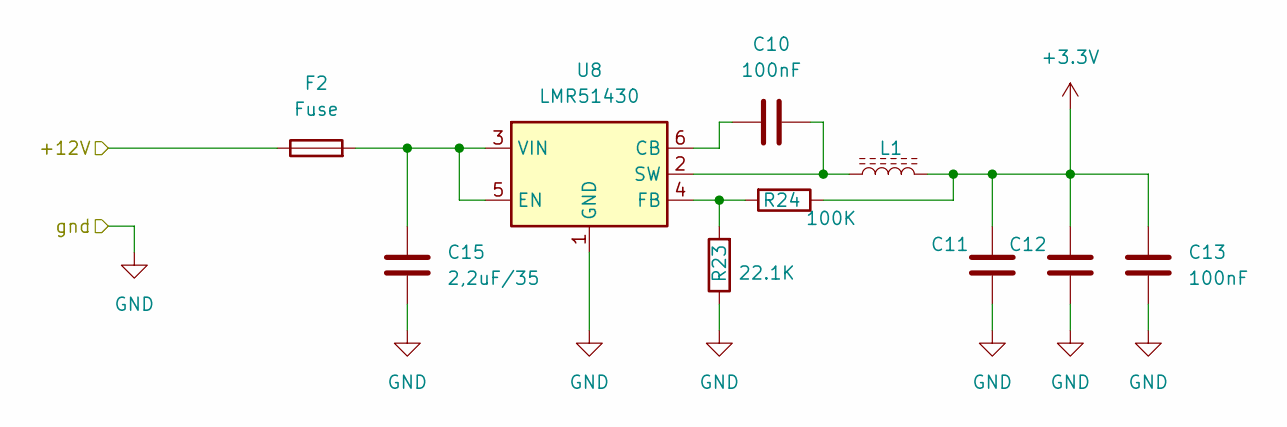
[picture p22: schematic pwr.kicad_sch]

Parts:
C10, C13: 100nF; C_0603_1608Metric_Pad1.08x0.95mm_HandSolder
C11, C12: CL10X106MO8NRNC; C_0603_1608Metric_Pad1.08x0.95mm_HandSolder
C15: 2,2uF/35; C_0603_1608Metric_Pad1.08x0.95mm_HandSolder
F2: Fuse; Fuse_1206_3216Metric_Pad1.42x1.75mm_HandSolder
L1: LQH5BPN4R7NT0L; L_APV_ANR5020
R23: 22.1K; R_0603_1608Metric_Pad0.98x0.95mm_HandSolder
R24: 100K; R_0603_1608Metric_Pad0.98x0.95mm_HandSolder
U8: LMR51430; SOT-23-6

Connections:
+3.3V: C11.2, C12.2, C13.1, L1.2, R24.1; also elsewhere on the board
+12V: F2.1; also elsewhere on the board
GND: C11.1, C12.1, C13.2, C15.2, R23.1, U8.1 (GND); also elsewhere on the board
unnamed: C10.1, U8.6 (CB)
unnamed: C15.1, F2.2, U8.3 (VIN), U8.5 (EN)
unnamed: R23.2, R24.2, U8.4 (FB)
unnamed: C10.2, L1.1, U8.2 (SW)

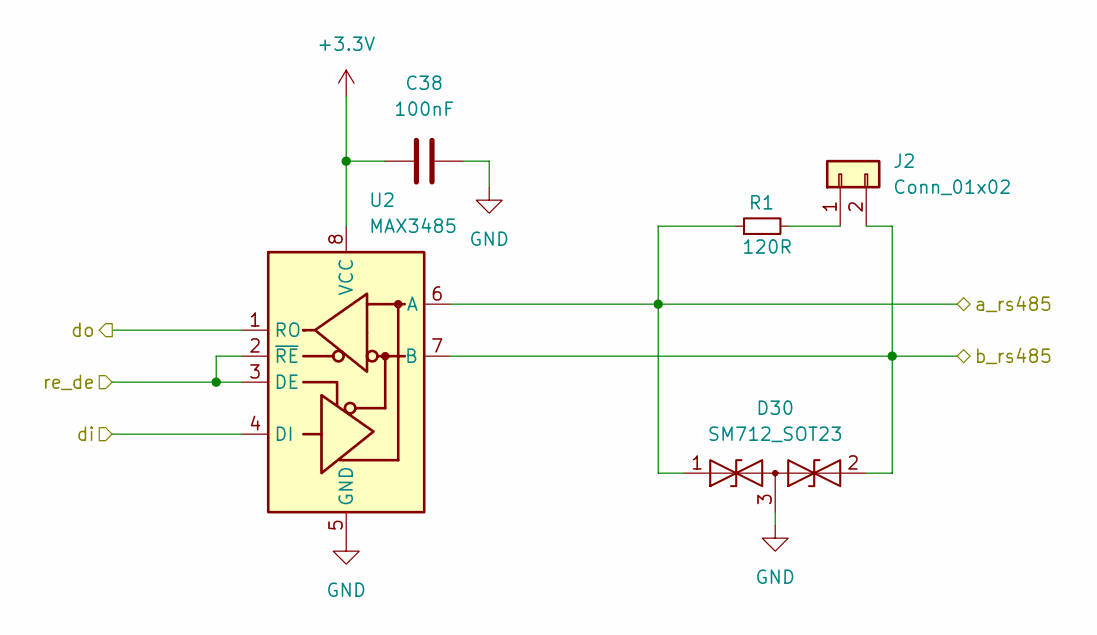
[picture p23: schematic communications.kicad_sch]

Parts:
C38: 100nF; C_0603_1608Metric_Pad1.08x0.95mm_HandSolder
D30: SM712_SOT23; SOT-23
J2: Conn_01x02; PinHeader_1x02_P2.54mm_Vertical
R1: 120R; R_0603_1608Metric_Pad0.98x0.95mm_HandSolder
U2: MAX3485; SOIC-8_3.9x4.9mm_P1.27mm

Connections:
+3.3V: C38.2, U2.8 (VCC); also elsewhere on the board
/re_de: U2.2 (~RE), U2.3 (DE); also elsewhere on the board
/rs_a: D30.1 (A1), R1.1, U2.6 (A); also elsewhere on the board
/rs_b: D30.2 (A2), J2.2, U2.7 (B); also elsewhere on the board
/u2_rx: U2.1 (RO); also elsewhere on the board
/u2_tx: U2.4 (DI); also elsewhere on the board
GND: C38.1, D30.3 (common), U2.5 (GND); also elsewhere on the board
unnamed: J2.1, R1.2

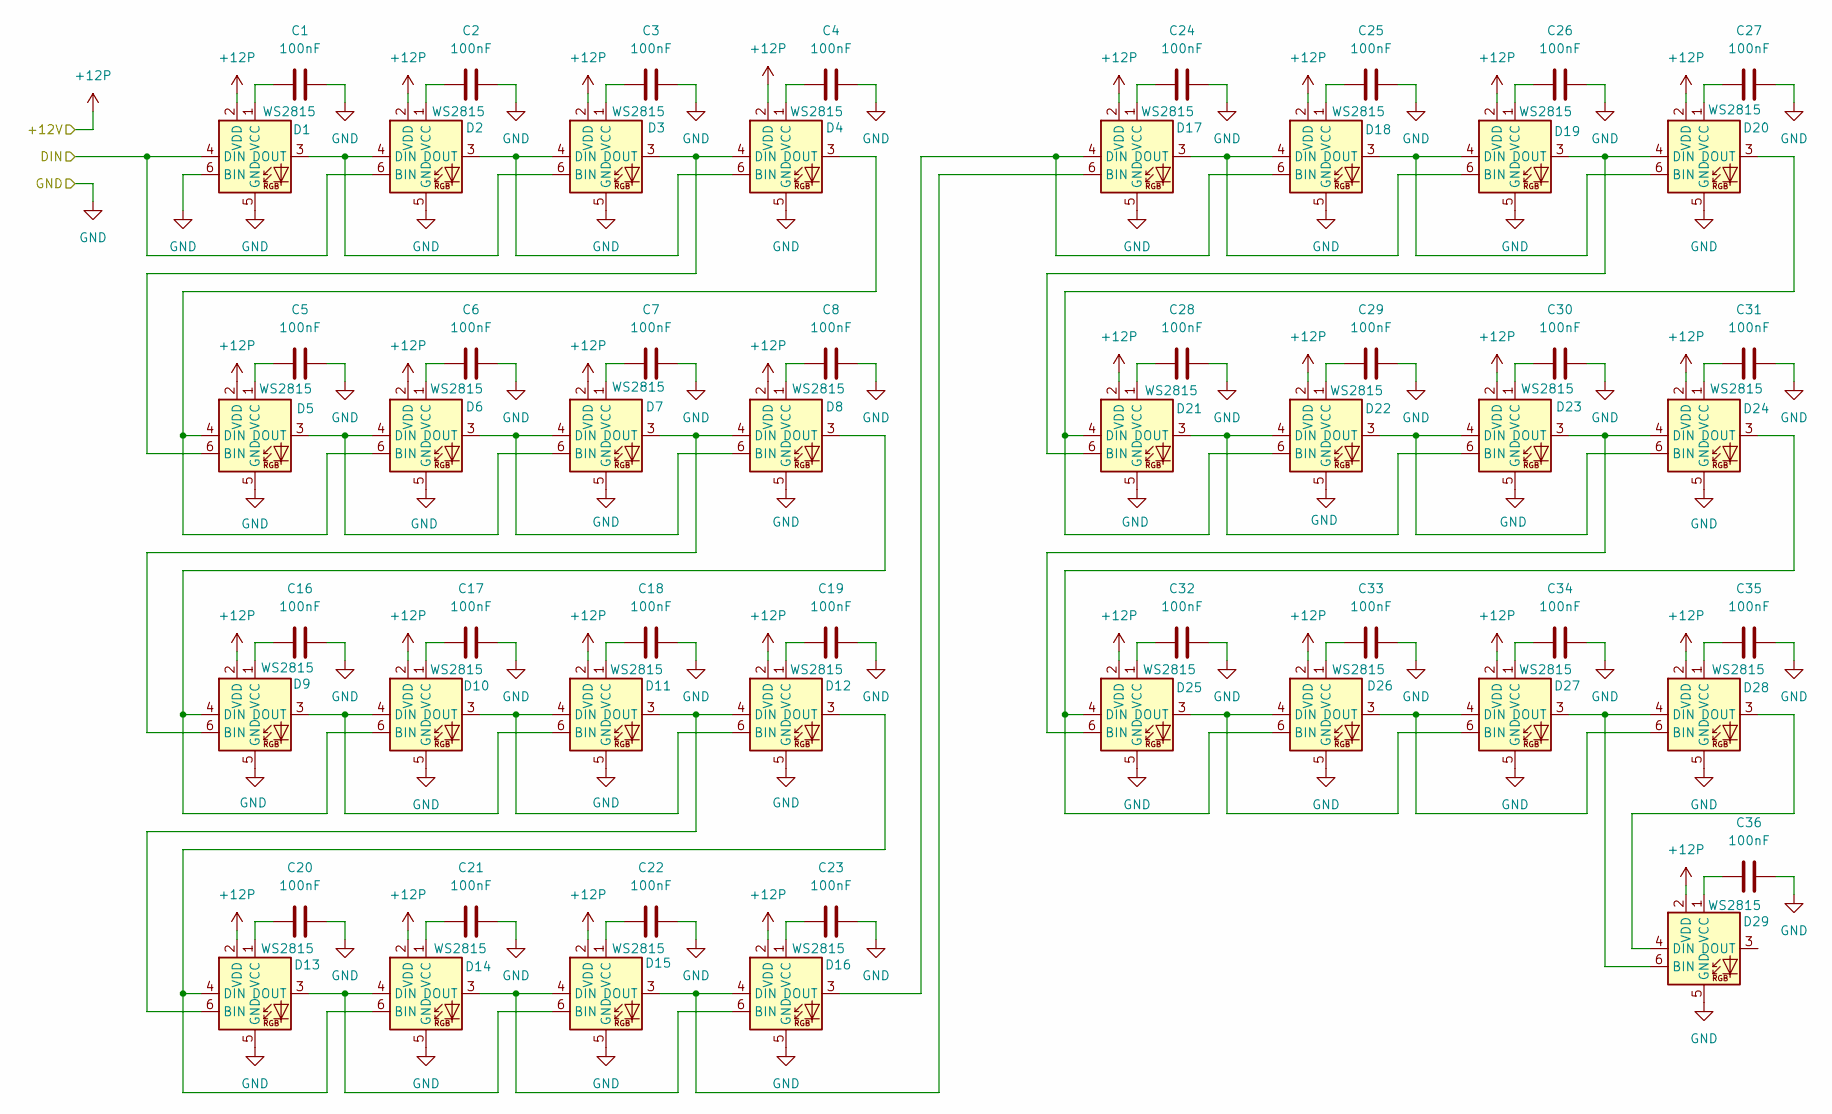
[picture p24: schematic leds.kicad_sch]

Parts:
C1, C2, C3, C4, C5, C6, C7, C8, C16, C17, C18, C19, C20, C21, C22, C23, C24, C25, C26, C27, C28, C29, C30, C31, C32, C33, C34, C35, C36: 100nF; C_0603_1608Metric_Pad1.08x0.95mm_HandSolder
D1, D2, D3, D4, D5, D6, D7, D8, D9, D10, D11, D12, D13, D14, D15, D16, D17, D18, D19, D20, D21, D22, D23, D24, D25, D26, D27, D28, D29: WS2815; LED_RGB_5050-6

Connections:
+12V: D1.2 (VDD), D2.2 (VDD), D3.2 (VDD), D4.2 (VDD), D5.2 (VDD), D6.2 (VDD), D7.2 (VDD), D8.2 (VDD), D9.2 (VDD), D10.2 (VDD), D11.2 (VDD), D12.2 (VDD), D13.2 (VDD), D14.2 (VDD), D15.2 (VDD), D16.2 (VDD), D17.2 (VDD), D18.2 (VDD), D19.2 (VDD), D20.2 (VDD), D21.2 (VDD), D22.2 (VDD), D23.2 (VDD), D24.2 (VDD), D25.2 (VDD), D26.2 (VDD), D27.2 (VDD), D28.2 (VDD), D29.2 (VDD); also elsewhere on the board
/data_in: D1.4 (DIN), D2.6 (BIN); also elsewhere on the board
GND: C1.1, C2.1, C3.1, C4.1, C5.1, C6.1, C7.1, C8.1, C16.1, C17.1, C18.1, C19.1, C20.1, C21.1, C22.1, C23.1, C24.1, C25.1, C26.1, C27.1, C28.1, C29.1, C30.1, C31.1, C32.1, C33.1, C34.1, C35.1, C36.1, D1.5 (GND), D1.6 (BIN), D2.5 (GND), D3.5 (GND), D4.5 (GND), D5.5 (GND), D6.5 (GND), D7.5 (GND), D8.5 (GND), D9.5 (GND), D10.5 (GND), D11.5 (GND), D12.5 (GND), D13.5 (GND), D14.5 (GND), D15.5 (GND), D16.5 (GND), D17.5 (GND), D18.5 (GND), D19.5 (GND), D20.5 (GND), D21.5 (GND), D22.5 (GND), D23.5 (GND), D24.5 (GND), D25.5 (GND), D26.5 (GND), D27.5 (GND), D28.5 (GND), D29.5 (GND); also elsewhere on the board
unnamed: D1.3 (DOUT), D2.4 (DIN), D3.6 (BIN)
unnamed: C1.2, D1.1 (VCC)
unnamed: D2.3 (DOUT), D3.4 (DIN), D4.6 (BIN)
unnamed: C2.2, D2.1 (VCC)
unnamed: D3.3 (DOUT), D4.4 (DIN), D5.6 (BIN)
unnamed: C3.2, D3.1 (VCC)
unnamed: D4.3 (DOUT), D5.4 (DIN), D6.6 (BIN)
unnamed: C4.2, D4.1 (VCC)
unnamed: D5.3 (DOUT), D6.4 (DIN), D7.6 (BIN)
unnamed: C5.2, D5.1 (VCC)
unnamed: D6.3 (DOUT), D7.4 (DIN), D8.6 (BIN)
unnamed: C6.2, D6.1 (VCC)
unnamed: D7.3 (DOUT), D8.4 (DIN), D9.6 (BIN)
unnamed: C7.2, D7.1 (VCC)
unnamed: C8.2, D8.1 (VCC)
unnamed: C16.2, D9.1 (VCC)
unnamed: D8.3 (DOUT), D9.4 (DIN), D10.6 (BIN)
unnamed: D9.3 (DOUT), D10.4 (DIN), D11.6 (BIN)
unnamed: D10.3 (DOUT), D11.4 (DIN), D12.6 (BIN)
unnamed: C17.2, D10.1 (VCC)
unnamed: D11.3 (DOUT), D12.4 (DIN), D13.6 (BIN)
unnamed: C18.2, D11.1 (VCC)
unnamed: D12.3 (DOUT), D13.4 (DIN), D14.6 (BIN)
unnamed: C19.2, D12.1 (VCC)
unnamed: D13.3 (DOUT), D14.4 (DIN), D15.6 (BIN)
unnamed: C20.2, D13.1 (VCC)
unnamed: D14.3 (DOUT), D15.4 (DIN), D16.6 (BIN)
unnamed: C21.2, D14.1 (VCC)
unnamed: D15.3 (DOUT), D16.4 (DIN), D17.6 (BIN)
unnamed: C22.2, D15.1 (VCC)
unnamed: D16.3 (DOUT), D17.4 (DIN), D18.6 (BIN)
unnamed: C23.2, D16.1 (VCC)
unnamed: D17.3 (DOUT), D18.4 (DIN), D19.6 (BIN)
unnamed: C24.2, D17.1 (VCC)
unnamed: D18.3 (DOUT), D19.4 (DIN), D20.6 (BIN)
unnamed: C25.2, D18.1 (VCC)
unnamed: D19.3 (DOUT), D20.4 (DIN), D21.6 (BIN)
unnamed: C26.2, D19.1 (VCC)
unnamed: D20.3 (DOUT), D21.4 (DIN), D22.6 (BIN)
unnamed: C27.2, D20.1 (VCC)
unnamed: D21.3 (DOUT), D22.4 (DIN), D23.6 (BIN)
unnamed: C28.2, D21.1 (VCC)
unnamed: D22.3 (DOUT), D23.4 (DIN), D24.6 (BIN)
unnamed: C29.2, D22.1 (VCC)
unnamed: D23.3 (DOUT), D24.4 (DIN), D25.6 (BIN)
unnamed: C30.2, D23.1 (VCC)
unnamed: D24.3 (DOUT), D25.4 (DIN), D26.6 (BIN)
unnamed: C31.2, D24.1 (VCC)
unnamed: D25.3 (DOUT), D26.4 (DIN), D27.6 (BIN)
unnamed: C32.2, D25.1 (VCC)
unnamed: D26.3 (DOUT), D27.4 (DIN), D28.6 (BIN)
unnamed: C33.2, D26.1 (VCC)
unnamed: D27.3 (DOUT), D28.4 (DIN), D29.6 (BIN)
unnamed: C34.2, D27.1 (VCC)
unnamed: D28.3 (DOUT), D29.4 (DIN)
unnamed: C35.2, D28.1 (VCC)
unnamed: C36.2, D29.1 (VCC)

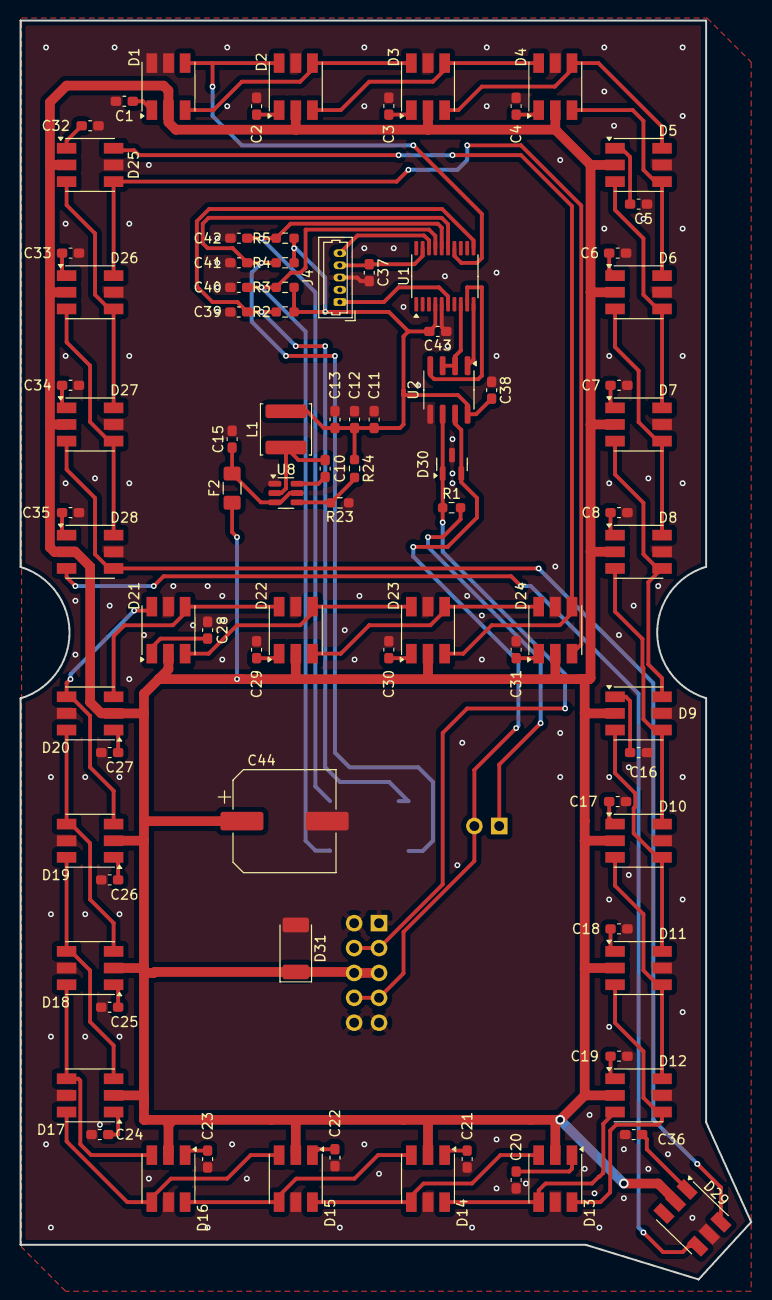
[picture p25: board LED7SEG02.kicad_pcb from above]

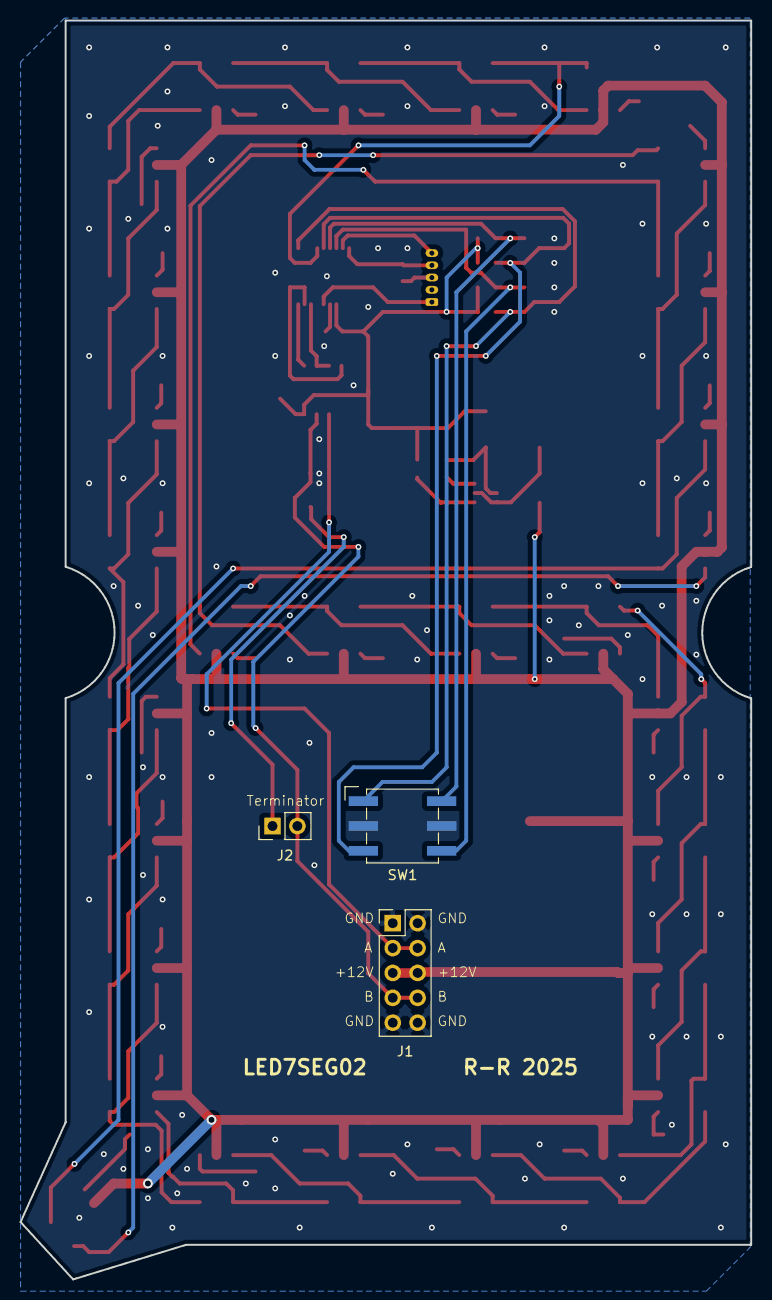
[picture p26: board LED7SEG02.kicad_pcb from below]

Board: 2 copper layers, 74.6 x 128.5 mm, 89 parts (3 on the bottom side), 78 nets.

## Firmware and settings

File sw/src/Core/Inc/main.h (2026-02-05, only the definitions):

#define addr_0_Pin GPIO_PIN_4
#define addr_0_GPIO_Port GPIOA
#define WS2815_Pin GPIO_PIN_7
#define WS2815_GPIO_Port GPIOA
#define addr_2_Pin GPIO_PIN_0
#define addr_2_GPIO_Port GPIOB
#define addr_3_Pin GPIO_PIN_11
#define addr_3_GPIO_Port GPIOA
#define addr_1_Pin GPIO_PIN_12
#define addr_1_GPIO_Port GPIOA

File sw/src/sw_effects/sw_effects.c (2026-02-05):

/**
 * @file sw_effects.c
 * @brief Visual effects implementation for 7-segment WS2815 LED display
 * @author LED7SEG02 Project
 */

#include "sw_effects.h"
#include "sw_ws2815.h"
#include <math.h>

/**
 * @brief Initialize effects module
 */
void Effects_Init(void)
{
    // Nothing to initialize yet
    // Future: Could initialize timers for automatic animation
}

/**
 * @brief Convert HSV color to RGB
 * @param h Hue (0-255)
 * @param s Saturation (0-255)
 * @param v Value/Brightness (0-255)
 * @return WS2815_Color_t RGB color structure
 */
WS2815_Color_t Effects_HSV_to_RGB(uint8_t h, uint8_t s, uint8_t v)
{
    WS2815_Color_t rgb;
    uint8_t region, remainder, p, q, t;

    if (s == 0) {
        // Achromatic (grey)
        rgb.r = v;
        rgb.g = v;
        rgb.b = v;
        return rgb;
    }

    region = h / 43;  // 0-5
    remainder = (h - (region * 43)) * 6;

    p = (v * (255 - s)) >> 8;
    q = (v * (255 - ((s * remainder) >> 8))) >> 8;
    t = (v * (255 - ((s * (255 - remainder)) >> 8))) >> 8;

    switch (region) {
        case 0:
            rgb.r = v; rgb.g = t; rgb.b = p;
            break;
        case 1:
            rgb.r = q; rgb.g = v; rgb.b = p;
            break;
        case 2:
            rgb.r = p; rgb.g = v; rgb.b = t;
            break;
        case 3:
            rgb.r = p; rgb.g = q; rgb.b = v;
            break;
        case 4:
            rgb.r = t; rgb.g = p; rgb.b = v;
            break;
        default:  // case 5:
            rgb.r = v; rgb.g = p; rgb.b = q;
            break;
    }

    return rgb;
}

/**
 * @brief Rainbow effect - cycles through all colors on the display
 */
int Effects_Rainbow(uint8_t step)
{
    // Create rainbow effect where each LED has a different hue
    // All LEDs cycle through the rainbow together

    for (uint8_t i = 0; i < 29; i++) {
        // Offset each LED's hue slightly for a gradient effect
        uint8_t hue = step + (i * 8);  // 8 = 255/29 for even distribution
        WS2815_Color_t color = Effects_HSV_to_RGB(hue, 255, 255);
        WS2815_SetLED(i, color);
    }

    return 0;
}

/**
 * @brief Spinning single LED effect for stand-by indication
 * Spins around the perimeter (segments forming digit 0: a,b,c,d,e,f)
 */
int Effects_SpinningLED(uint8_t position, WS2815_Color_t color)
{
    // LED mapping for perimeter (forming digit 0)
    // Segments: a -> b -> c -> d -> e -> f -> back to a
    const uint8_t perimeter_leds[24] = {
        // Segment a (top)
        0, 1, 2, 3,
        // Segment b (top right)
        4, 5, 6, 7,
        // Segment c (bottom right)
        8, 9, 10, 11,
        // Segment d (bottom)
        12, 13, 14, 15,
        // Segment e (bottom left)
        16, 17, 18, 19,
        // Segment f (top left) - reversed order for smooth motion
        27, 26, 25, 24
    };

    // Turn off all LEDs
    WS2815_Color_t black = {0, 0, 0};
    for (uint8_t i = 0; i < 29; i++) {
        WS2815_SetLED(i, black);
    }

    // Light up only the LED at the specified position on perimeter
    position = position % 24;  // Wrap around the perimeter (24 LEDs)
    WS2815_SetLED(perimeter_leds[position], color);

    return 0;
}

/**
 * @brief Breathing effect - fades in and out
 */
int Effects_Breathing(uint8_t step, WS2815_Color_t color)
{
    // Calculate brightness using sine wave for smooth breathing
    // step 0-255 maps to 0-360 degrees (or 0-2*PI radians)

    // Use triangle wave instead of sine for simplicity
    uint8_t brightness;
    if (step < 128) {
        // Fade in: 0 to 255
        brightness = step * 2;
    } else {
        // Fade out: 255 to 0
        brightness = (255 - step) * 2;
    }

    // Apply brightness to color
    WS2815_Color_t dimmed_color;
    dimmed_color.r = (color.r * brightness) / 255;
    dimmed_color.g = (color.g * brightness) / 255;
    dimmed_color.b = (color.b * brightness) / 255;

    // Set all LEDs to the dimmed color
    for (uint8_t i = 0; i < 29; i++) {
        WS2815_SetLED(i, dimmed_color);
    }

    return 0;
}

/**
 * @brief Segment chase effect - lights up segments in sequence
 */
int Effects_SegmentChase(uint8_t step, WS2815_Color_t color)
{
    WS2815_Color_t black = {0, 0, 0};

    // Turn off all segments
    for (uint8_t i = 0; i < 7; i++) {
        WS2815_SetSegment(i, black);
    }

    // Light up current segment
    uint8_t segment = step % 7;  // Wrap around after segment g
    WS2815_SetSegment(segment, color);

    return 0;
}

/**
 * @brief Loading bar effect - fills segments progressively
 */
int Effects_LoadingBar(uint8_t progress, WS2815_Color_t color)
{
    // progress: 0-100 percentage
    // Maps to segments: 0% = none, 100% = all 7 lit

    WS2815_Color_t black = {0, 0, 0};
    uint8_t segments_lit = (progress * 7) / 100;

    // Segment order for loading: a, b, c, d, e, f, g (clockwise)
    const uint8_t segment_order[7] = {0, 1, 2, 3, 4, 5, 6};

    for (uint8_t i = 0; i < 7; i++) {
        if (i < segments_lit) {
            WS2815_SetSegment(segment_order[i], color);
        } else {
            WS2815_SetSegment(segment_order[i], black);
        }
    }

    return 0;
}

/**
 * @brief Knight Rider effect - LED bounces back and forth
 */
int Effects_KnightRider(uint8_t position, WS2815_Color_t color)
{
    WS2815_Color_t black = {0, 0, 0};

    // Clear all LEDs
    for (uint8_t i = 0; i < 29; i++) {
        WS2815_SetLED(i, black);
    }

    // Map position 0-56 to LED 0-28 and back (bounce effect)
    uint8_t led_pos;
    if (position < 29) {
        led_pos = position;  // Forward
    } else {
        led_pos = 56 - position;  // Backward
    }

    // Main LED at full brightness
    WS2815_SetLED(led_pos, color);

    // Add trailing LEDs with decreasing brightness
    if (led_pos > 0) {
        WS2815_Color_t trail1 = {color.r/2, color.g/2, color.b/2};
        WS2815_SetLED(led_pos - 1, trail1);
    }
    if (led_pos > 1) {
        WS2815_Color_t trail2 = {color.r/4, color.g/4, color.b/4};
        WS2815_SetLED(led_pos - 2, trail2);
    }

    return 0;
}

/**
 * @brief Display digit with color cycling through spectrum (non-blocking)
 * @param digit Digit to display (0-9)
 * @param show_dp Show decimal point (0 = hide, 1 = show)
 * @param step Current color step (0-255, cycles through HSV spectrum)
 * @return 0 on success, negative on error
 *
 * This is a non-blocking function - call it repeatedly with incrementing step
 * to create a rainbow color cycling effect on the displayed digit.
 */
int Effects_RainbowDigit(uint8_t digit, uint8_t show_dp, uint8_t step)
{
    if (digit > 9) {
        return -1;  // Invalid digit
    }

    // Convert HSV hue to RGB color
    // step 0-255 cycles through full color spectrum
    WS2815_Color_t color = Effects_HSV_to_RGB(step, 255, 255);

    // Display the digit with current rainbow color
    WS2815_DisplayDigit(digit, color, show_dp);

    return 0;
}
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

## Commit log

2026-02-05 Intial commit
    [LED7SEG02.kicad_pcb, LED7SEG02.kicad_sch, LED7SEG02_Body.stl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]
2026-02-07 Correct project documentation structure.
    [LED7SEG02.kicad_pcb, LED7SEG02.kicad_sch]
2026-02-07 Update actions products
    [LED7SEG02-B_Adhesive.dxf, LED7SEG02-B_Courtyard.dxf, LED7SEG02-B_Cu.dxf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]
2026-10-01 Update doc/assets submodule branch from KiCADv8 to KiCADv10
    Upgrades the doc/assets submodule to the KiCADv10 branch, which brings
    updated GitHub Actions workflows (KiBot v2_dk10, multi-PCB matrix/discover
    job, MLAB 3D models, CAD postprocess, fixed UPDATE_REPO guard).
2026-10-01 Fix update_actions.yml: upgrade to KiCADv10 (checkout@v4, ref fallback)

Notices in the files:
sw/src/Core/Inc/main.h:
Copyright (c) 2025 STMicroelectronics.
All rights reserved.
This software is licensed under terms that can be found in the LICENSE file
